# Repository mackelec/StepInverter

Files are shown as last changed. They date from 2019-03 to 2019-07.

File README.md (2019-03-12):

# StepInverter
These are the Files and Tools for my Step Inverter based on Tony's (WarpSpeed) designs and ideas.
You'll find me, "MackOffGrid" and Tony, "WarpSpeed" on https://www.thebackshed.com/forum/forum_topics.asp?FID=4 

Please keep in mind that the spreadsheet, software and schematics are not polished for public consumption, I created them for myself to get the job done.

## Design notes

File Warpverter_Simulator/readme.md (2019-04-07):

# Warpverter Simulator

The simulator reads the signals from a Warpverter of any kind, and produces an analog output that you can view using a Scope.  It can also capture a frame of data and send the data to a PC.

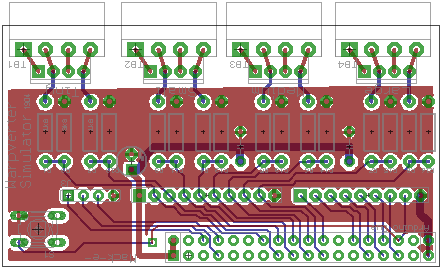
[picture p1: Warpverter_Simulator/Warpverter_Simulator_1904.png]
Warpverter Simulator


## Instruction

This PCB plugs into the 38 pin header of tha Aduno DUE.

Then plug the outputs of Tony's Inverter, or stm32_Warpverter, into the matching connectors of the simulator PCB.
Connect your oscilloscope to DAC0 of the DUE to see the synthesized waveform.

Press the button on the simulator PCB and it will grab a frame of data and send it (by USB) to your PC.  Using the Arduino IDE serial monitor is the easiest way.

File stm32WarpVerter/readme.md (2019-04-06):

# stm32_WarpVerter

This project is based on Tony's "WarpSpeed" inverter, aka the "WarpVerter"

This version is processor based, on the STM32F103 BluePill module.

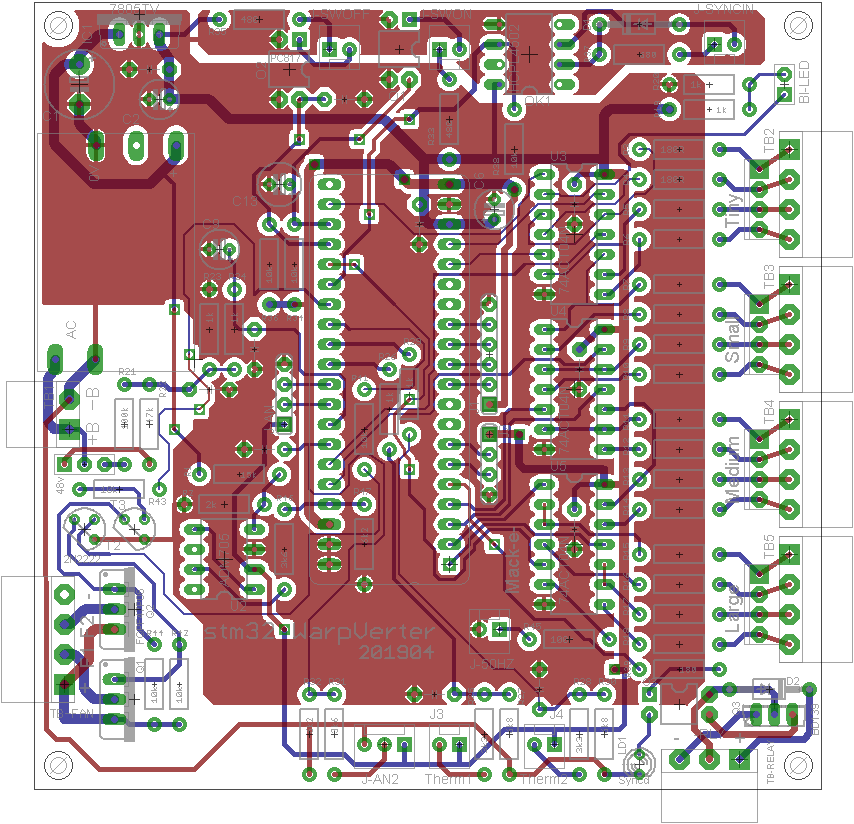
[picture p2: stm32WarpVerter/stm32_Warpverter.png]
stm32WarpVerter


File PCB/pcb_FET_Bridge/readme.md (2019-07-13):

# MOSFET Bridge PCB  

This PCB can be used as a Full H-Bridge or Half H-Bridge board.  Fet Driver board required.

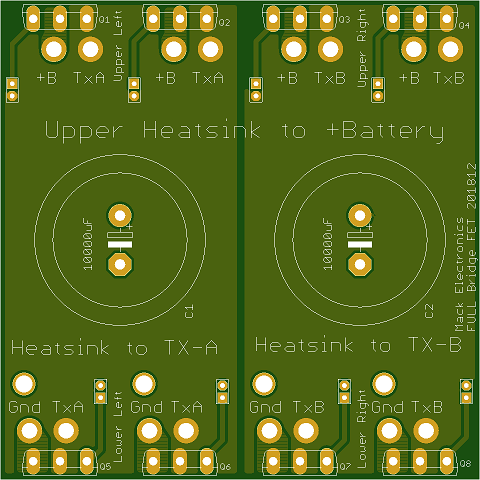
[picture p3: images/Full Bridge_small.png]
Full Bridge


#### Last Tested PCB

[Zip - Gerbers, Cad files 201812](https://github.com/mackelec/StepInverter/blob/master/PCB/pcb_FET_Bridge/FullBridgeFet_201812_2_complete.zip)

## Most Recent Version

 -  #### FBF_4Pin_201907-A
 -  Driver board connectors have been changed to 4 pin connectors.
 -  100k SMD (1206) Pulldowns added.  Not required - precautionary.
 -  Added Large Capacitor with Screw Terminals, (ALS70A513NF100 )[https://au.mouser.com/ProductDetail/80-ALS70A513NF100]
 -  [Zip - Gerbers, Cad Files FBF_4pin_201907](https://github.com/mackelec/StepInverter/blob/master/PCB/pcb_FET_Bridge/FullBridgeFet_4pin_201907A_complete.zip)
 -  Should be compatible with 2 Pin Driver Board.
 
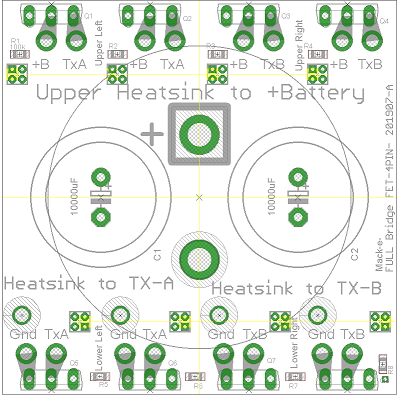
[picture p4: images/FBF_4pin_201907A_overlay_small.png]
FBF_4Pin_201907-A


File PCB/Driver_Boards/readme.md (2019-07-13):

#  Full Bridge Driver Board (201907-A)

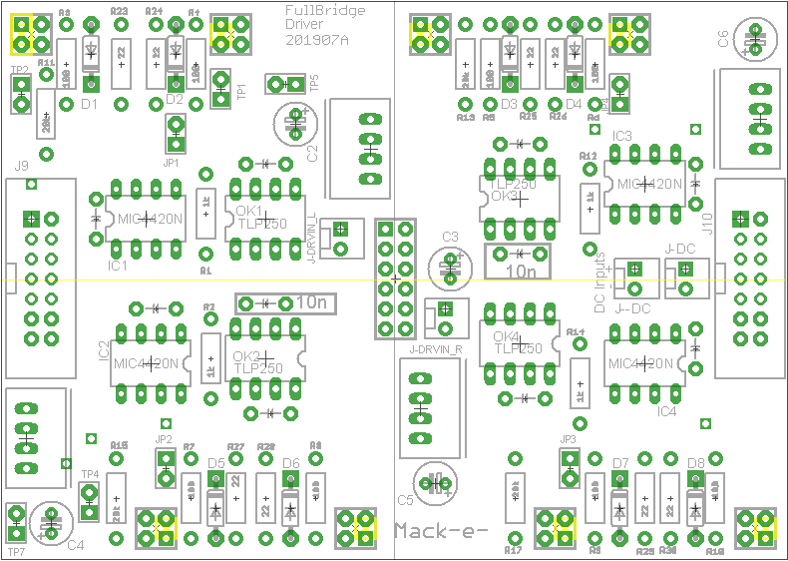
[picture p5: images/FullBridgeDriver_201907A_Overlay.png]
FullBridgeDriverBoard


#  Half Bridge Driver Board (201907)

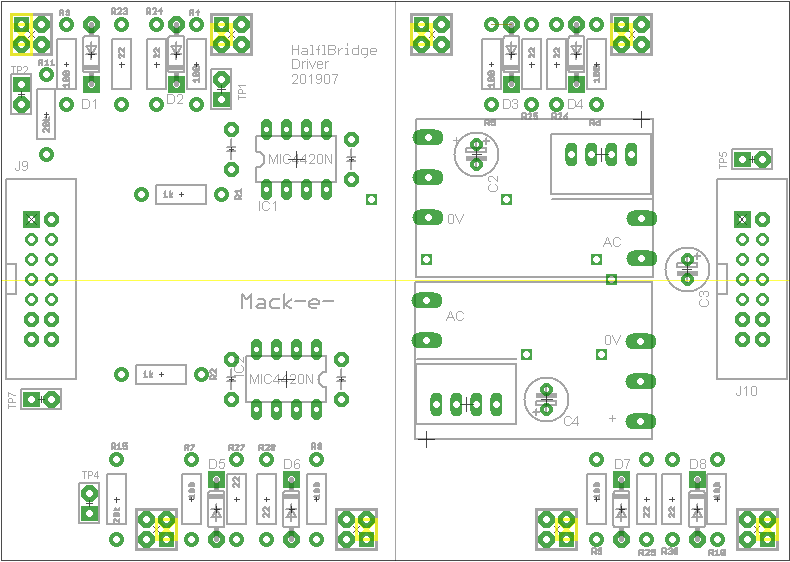
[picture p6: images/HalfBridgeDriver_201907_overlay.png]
HalfBridgeDriverBoard


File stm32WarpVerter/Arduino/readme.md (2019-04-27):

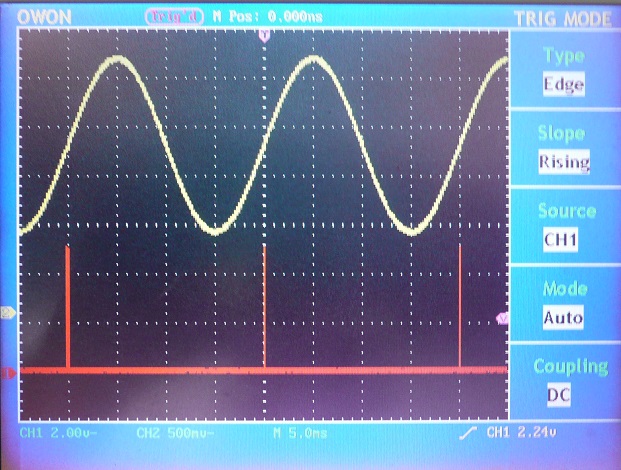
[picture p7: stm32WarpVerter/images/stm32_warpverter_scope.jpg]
Inverter View
 

###  Arduino Software

The software for the stm32_Warpverter is separated into two projects.

* # stm32_Warpverter project.  
  * This is the software which runs the stm32_Warpverter.  
  * The latest version is [stm32_warpverter_009](https://github.com/mackelec/StepInverter/tree/master/stm32WarpVerter/Arduino/stm32_Warpverter/stm32_Warpverter_009)
  *  This software runs on stm32F103C8 "Blue Pill" and the [stm32_Warpverter PCB](https://github.com/mackelec/StepInverter/tree/master/stm32WarpVerter/PCB).
  *  The STM32 BluePill has a generous Flash Rom capacity - notional 64k but most seem to have 128k. This software makes extensive use of pre-calculated lookup tables making full use of available Flash Rom..  
  *  Tables are produced by the "Print_Tables" arduino software.  See Next Section.  
  *  Comprises all the features you need in a functional Inverter.
  *  Most features are configurable - mostly in the Print_Tables software.

* # Print_Tables project.  
  *  The latest version is [print_Tables_2c](https://github.com/mackelec/StepInverter/tree/master/stm32WarpVerter/Arduino/Print_Tables/print_Tables_02).
  *  The objective of this software is to take the User Settings and create "Tables" in the form of arrays.  
  *  The USER_Settings tab holds various setting that may be adjusted.  
  *  Upload and run the program on the BluePill.  
  *  The BluePill creates the required "Table" arrays for the stm32_Warpverter and exports the array data to the Serial port.  
  *  From the Serial Monitor the array data is copied and pasted into the stm32_Warpverter project.

## Features

* This software provides the functionality to acheive Tony's "WarpSpeed" Warpverter; a low distortion, four transformer, very low frequency, pure sine wave inverter.
* Open loop control of output voltage based on input voltage and input current.  
* Two 10k thermister inputs and corresponding PWM FAN outputs.  Fully configurable temperatures and control method: modulating PWM or Bang-Bang.
* Seperate ON and OFF inputs.  Off input can be used as external Fault input.
* Bi-Colour LED for ON-OFF status.
* InputCurrent - Fan function.  Two independant Input Current thresholds - when met will operate the two corresponding FANS. 
* Under and Over Input Voltage shut downs (configurable).
* Over Current shut down .
* 50Hz / 60Hz configurable. 
* External Syncronising input.  Using Poida's mains sync routine.  Should sync with other warpVerters accurately.
* 50Hz (60Hz) pulse output (approx 20uSec) will ensure accurate syncronising with other warpVerters.

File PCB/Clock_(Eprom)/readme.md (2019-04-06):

## Warpverter Clock PCB

This PCB contructs is the heart of the Warpverter.  It uses an Eprom to construct the four inverter drive signals.

### VER 201903

This is my latest version. Fixed an oops on the previous version.  Major changes to the micro port, uses a crystal module instead of a discrete circuit, added a sync connector for my experiment on three phase.  Added a Bi-colour LED for Run/Stop.  Changed the PSU supervisor to max705.

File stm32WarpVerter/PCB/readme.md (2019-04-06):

Zip Files contain EAGLE files and Gerber files.

For gerber viewer,  http://gerbv.geda-project.org/

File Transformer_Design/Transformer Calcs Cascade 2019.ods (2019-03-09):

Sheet: Cascade Design
Nominal Battery Voltage | 26.5
Vmax | 28
Vmin | 24
Nominal AC Voltage | 240
Nominal Power | 4500
Num Transformer Stages | 4
 |  |  |  | 4500 W |  | 3000 W |  | 1500 W |  | 500 W
Transformer # | Nom. Step Voltage | Nom RMS Voltage | Power | Cu Loss | Volt Drop | Cu Loss | Volt Drop | Cu Loss | Volt Drop | Cu Loss | Volt Drop
Tx1 | 229.068 | 162 | 3037.5 | 158 | 3 | 70 | 2 | 18 | 1 | 2 | 0
Tx2 | 76.356 | 54 | 1012.5 | 79 | 3 | 35 | 2 | 9 | 1 | 1 | 0
Tx3 | 25.452 | 18 | 337.5 | 39 | 2 | 17 | 1 | 4 | 1 | 0 | 0
Tx4 | 8.484 | 6 | 112.5 | 12 | 1 | 5 | 1 | 1 | 0 | 0 | 0
sum (check) | 339.36 | 240 | 4500 | 288 | 9 | 128 | 6 | 32 | 3 | 4 | 1
RMS (check) | 240
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

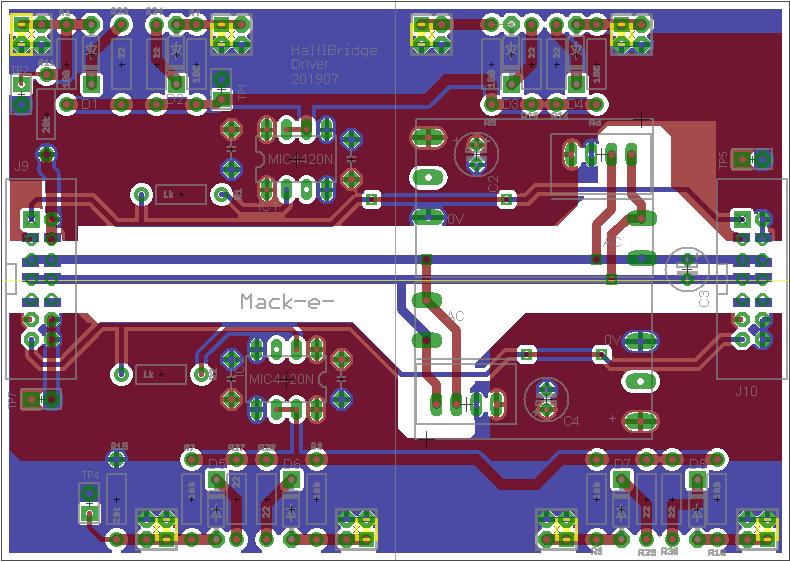
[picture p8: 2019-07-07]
images/HalfBridgeDriver_201907.png

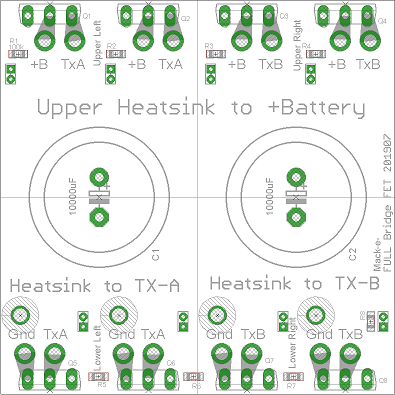
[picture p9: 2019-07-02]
images/FBF_201907_small.png

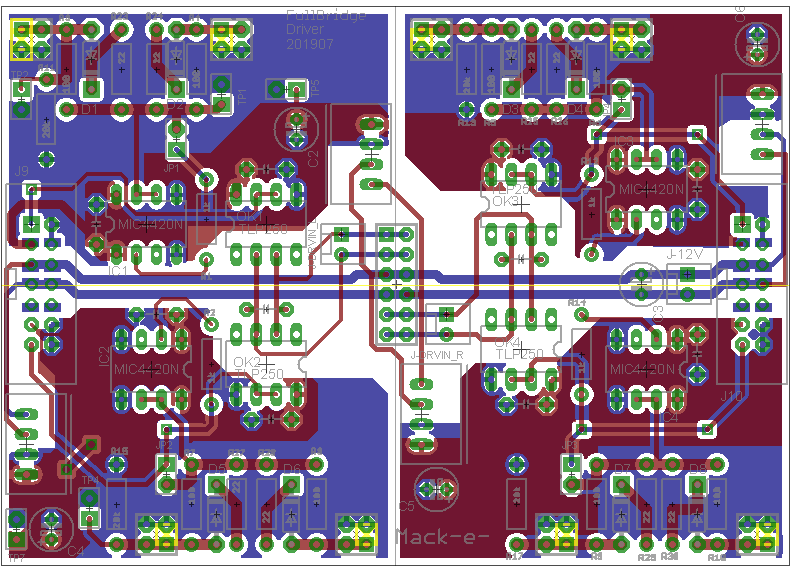
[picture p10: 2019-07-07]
images/FullBridgeDriver_201907.png

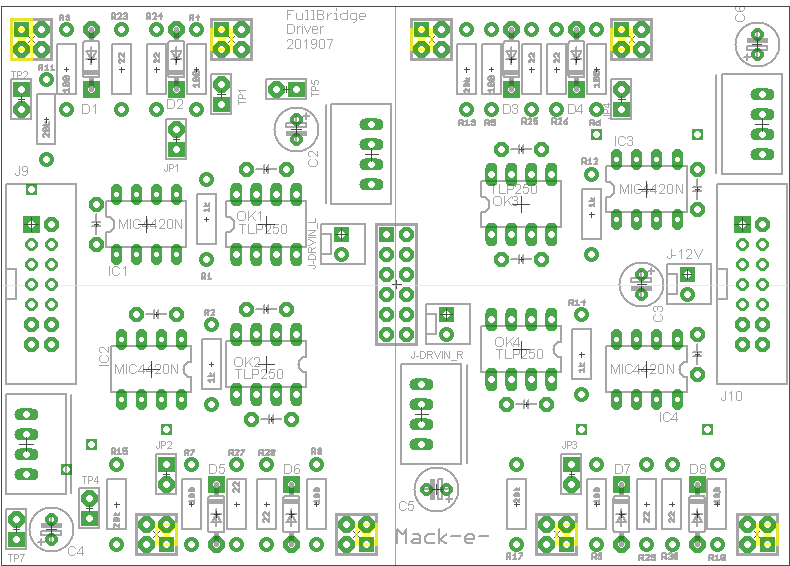
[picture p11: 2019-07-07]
images/FullBridgeDriver_201907_Overlay.png

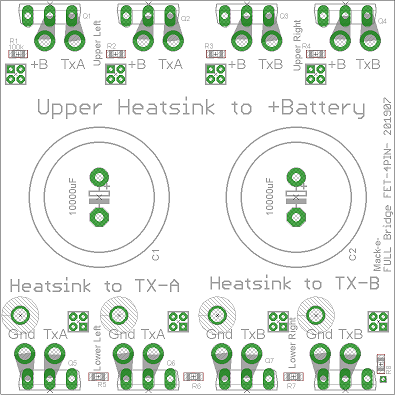
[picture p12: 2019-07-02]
images/FBF_4pin_201907_small.png

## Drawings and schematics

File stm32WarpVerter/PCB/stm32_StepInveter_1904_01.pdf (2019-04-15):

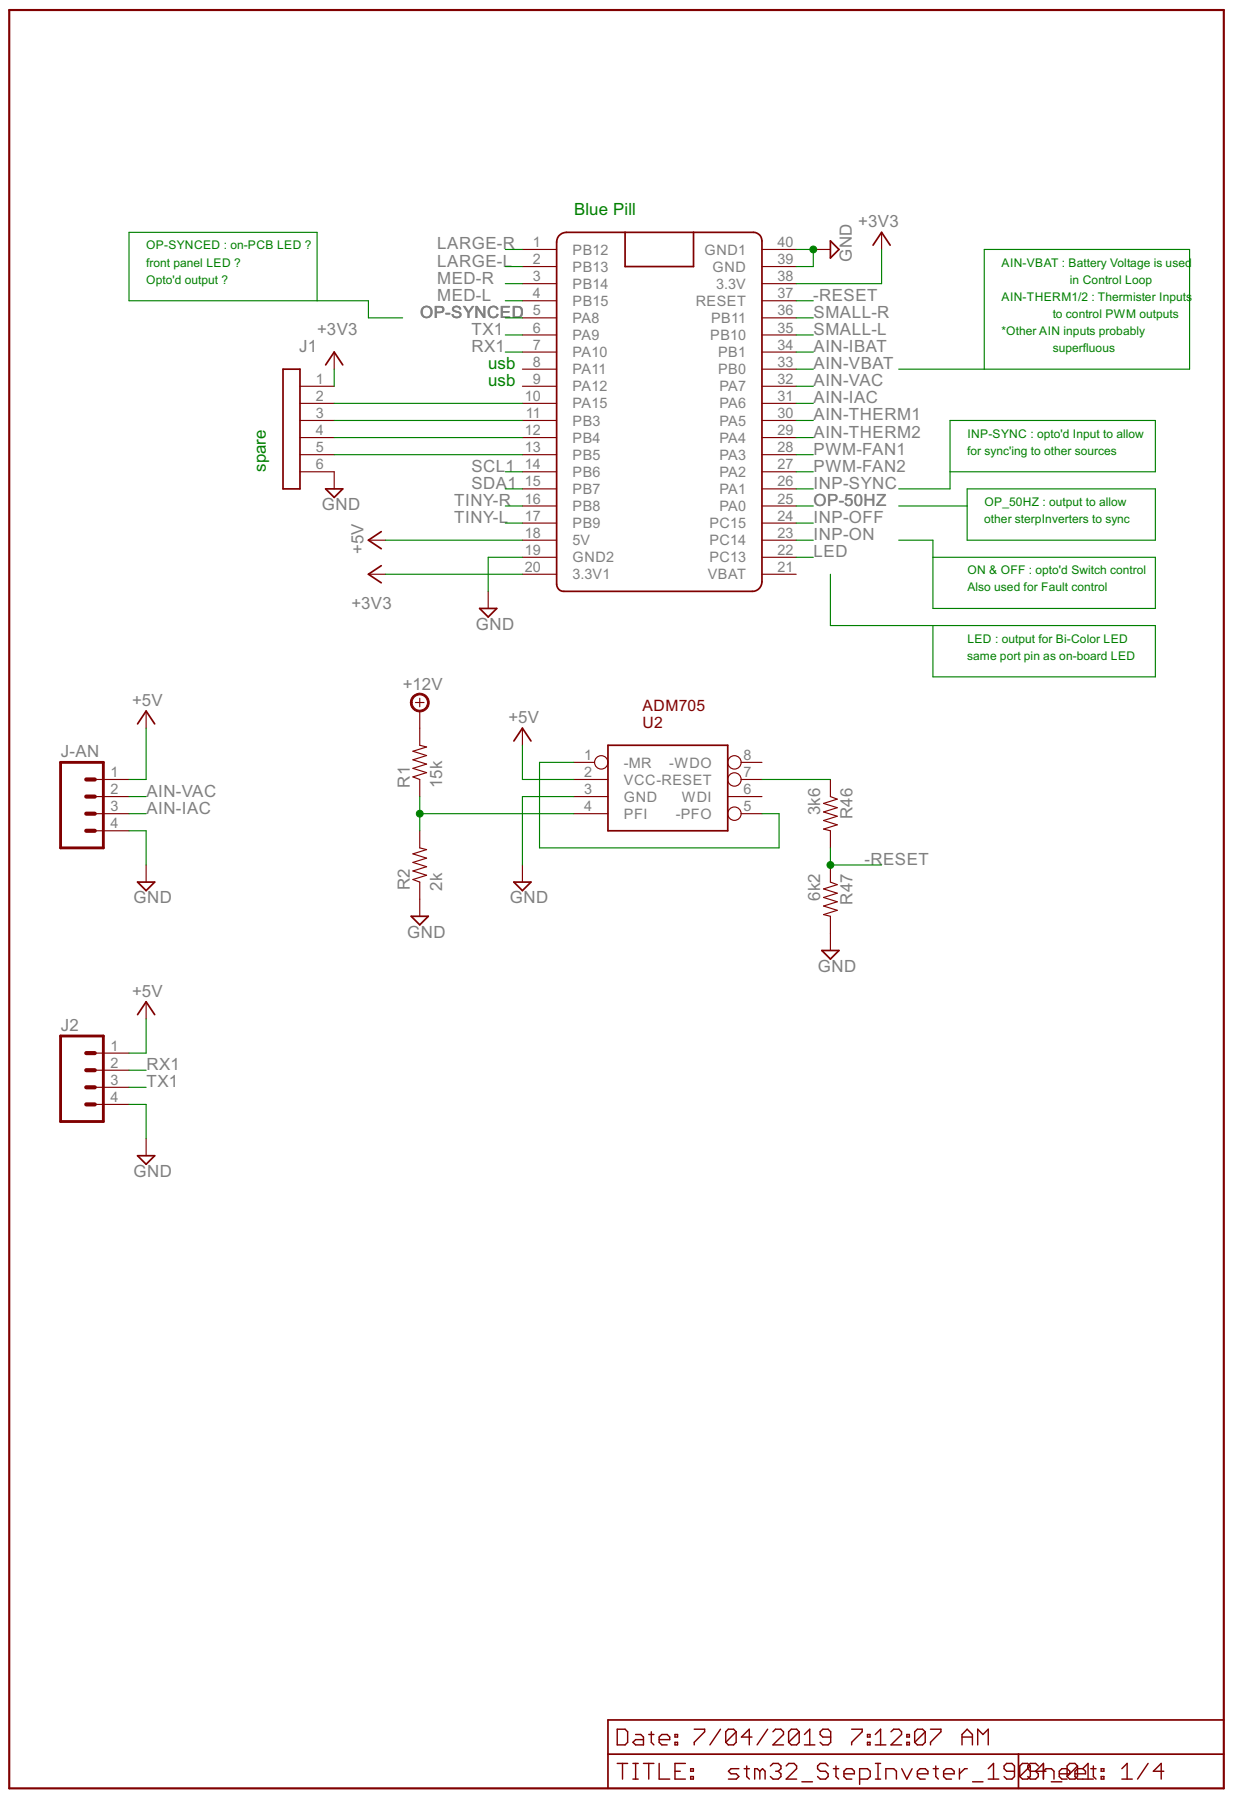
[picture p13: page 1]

OP-SYNCED : on-PCB LED ?

in Control Loop AIN-THERM1/2 : Thermister Inputs

*Other AIN inputs probably

to control PWM outputs

INP-SYNC : opto'd Input to allow
for sync'ing to other sources

OP_50HZ : output to allow
other sterpInverters to sync ON & OFF : opto'd Switch control Also used for Fault control LED : output for Bi-Color LED

same port pin as on-board LED

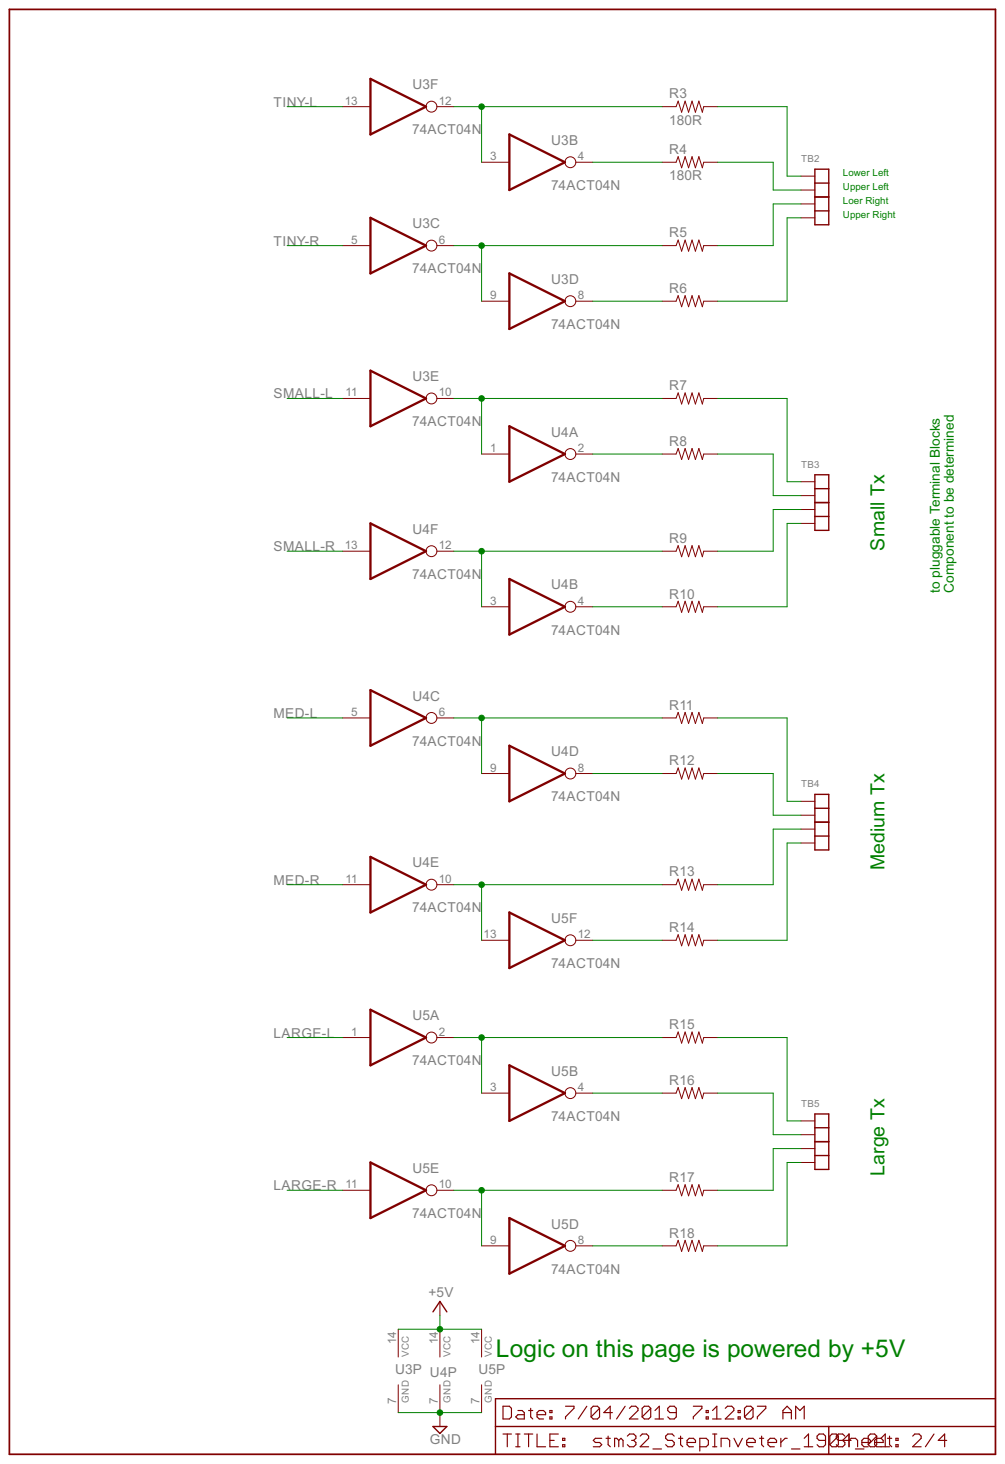
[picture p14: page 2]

Lower Left Upper Left Loer Right Upper Right

to pluggable Terminal Blocks Component to be determined

Logic on this page is powered by +5V

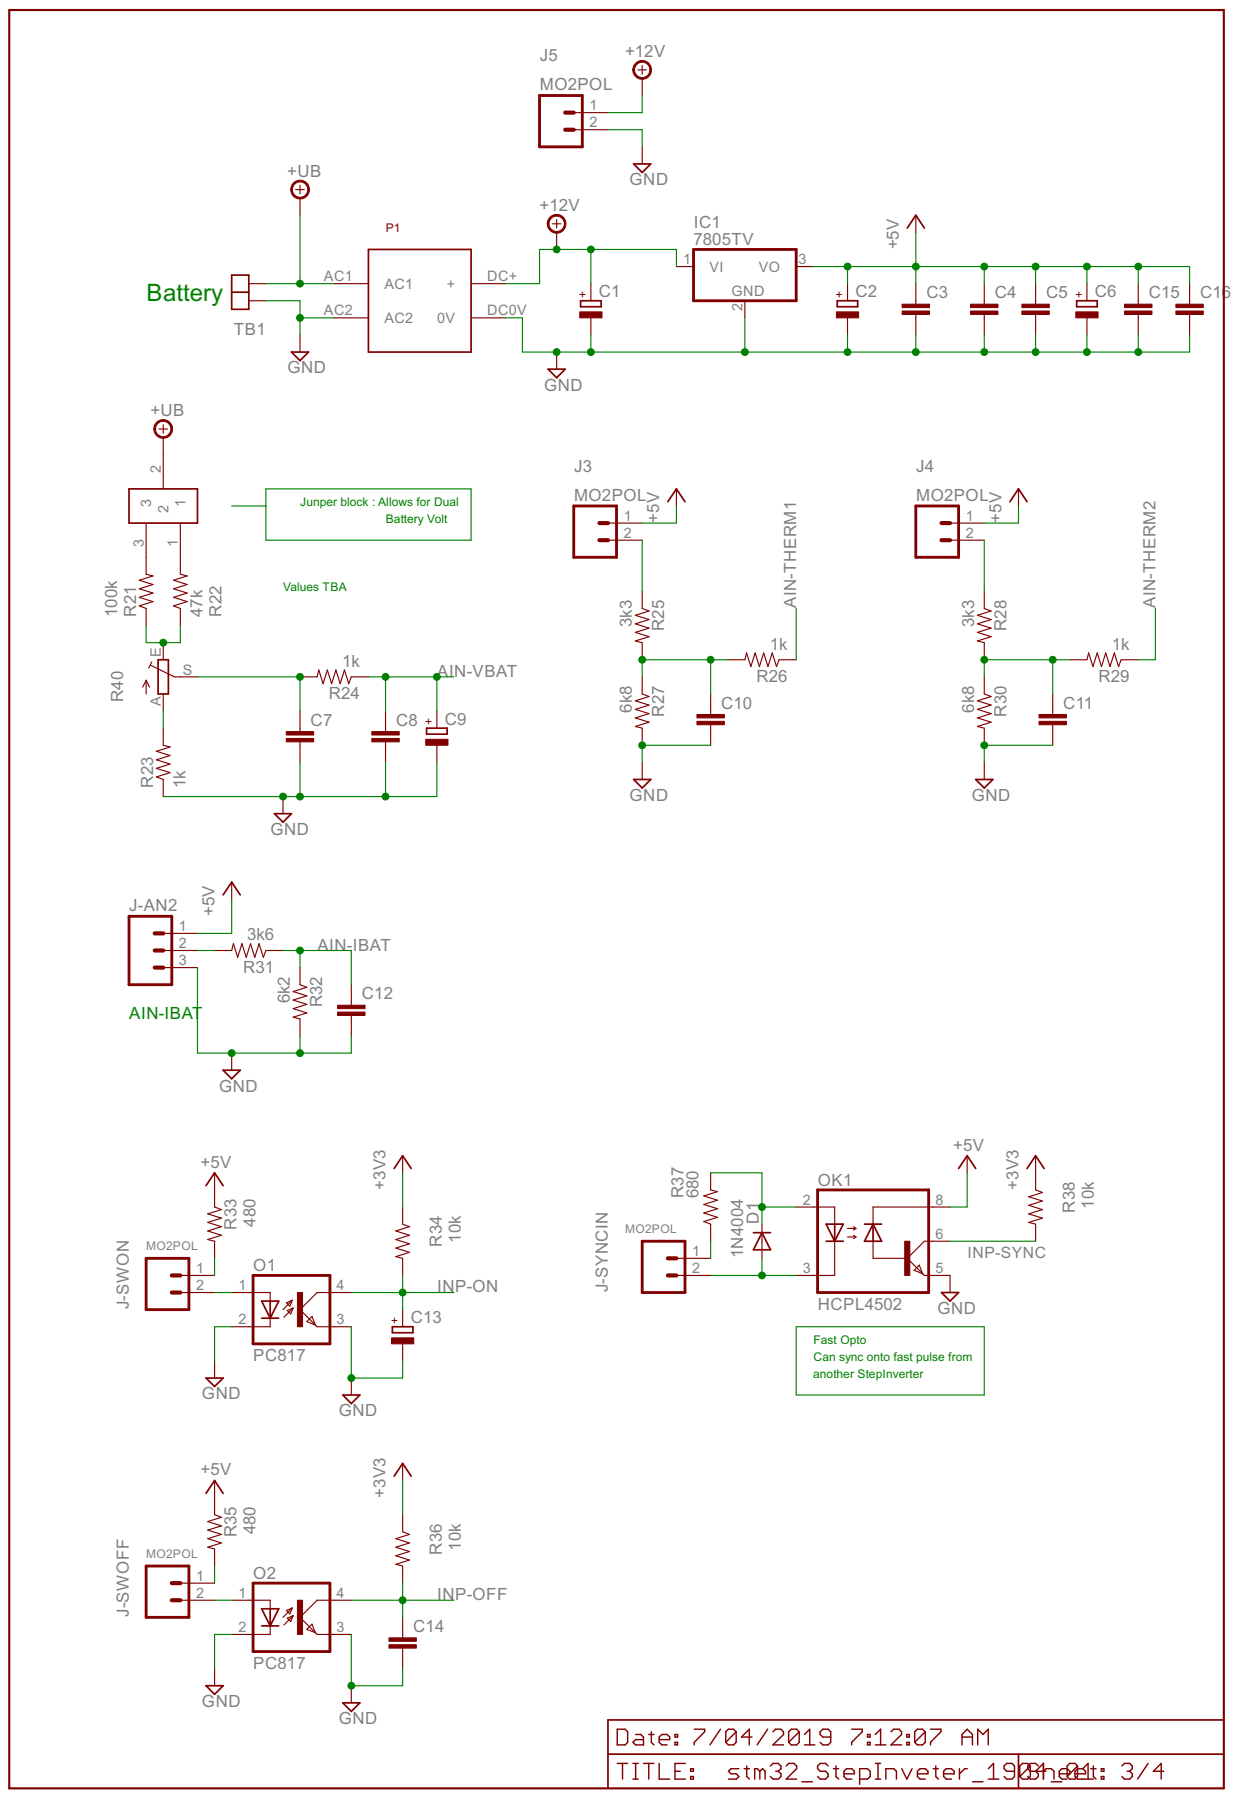
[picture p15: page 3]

Junper block : Allows for Dual Battery Volt

Fast Opto Can sync onto fast pulse from

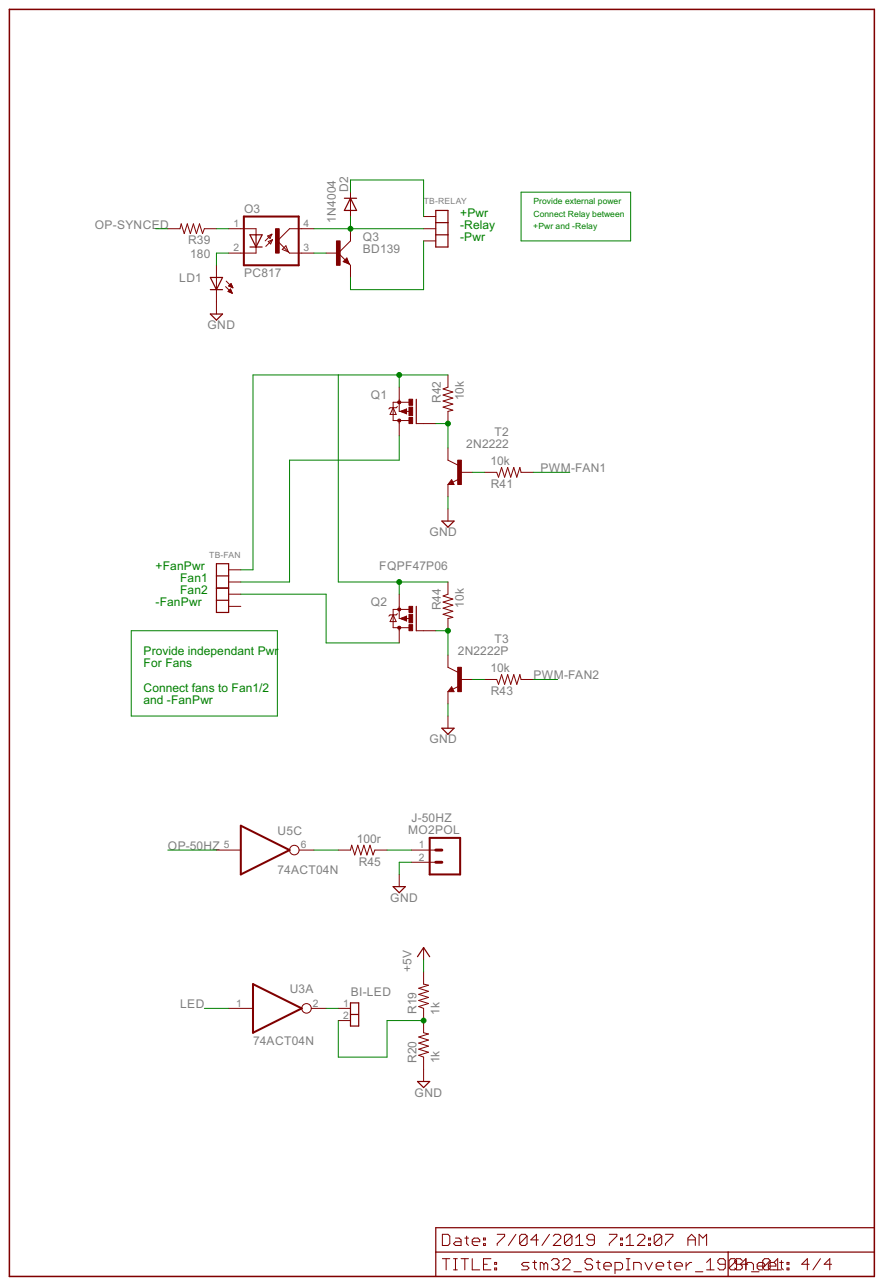
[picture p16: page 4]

Provide independant Pwr For Fans Connect fans to Fan1/2

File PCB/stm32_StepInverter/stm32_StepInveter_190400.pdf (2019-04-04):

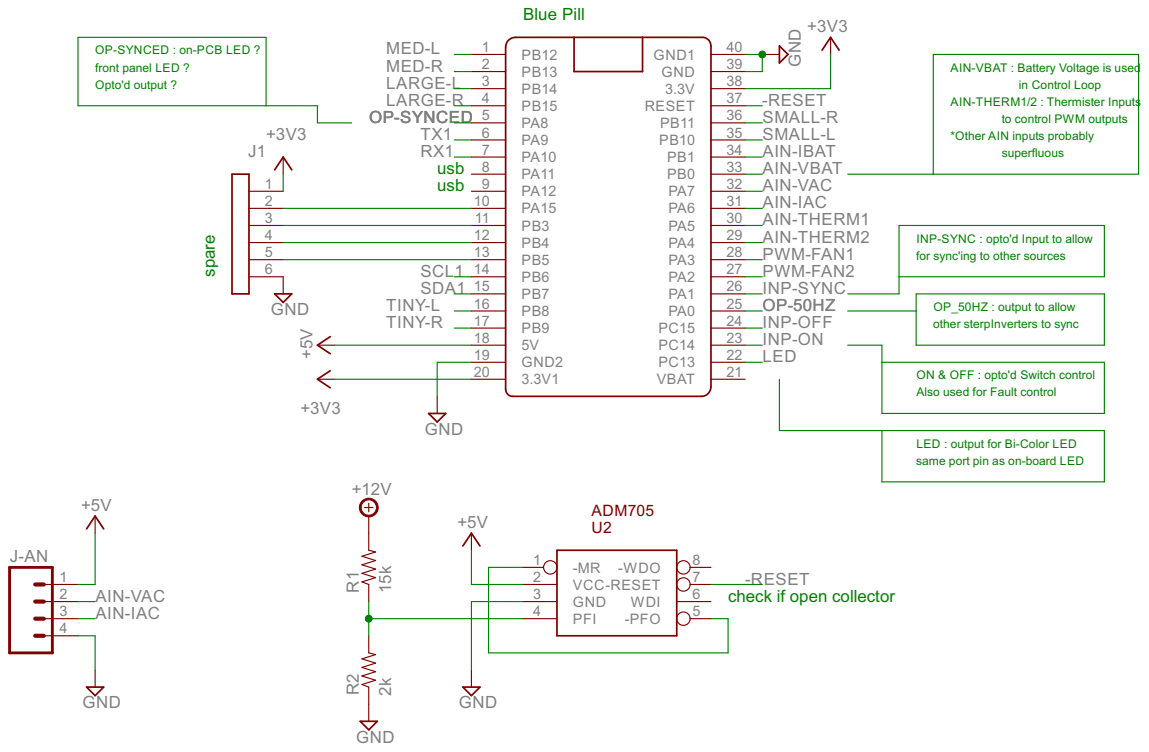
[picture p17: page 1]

OP-SYNCED : on-PCB LED ?

in Control Loop AIN-THERM1/2 : Thermister Inputs

*Other AIN inputs probably

to control PWM outputs

INP-SYNC : opto'd Input to allow
for sync'ing to other sources

OP_50HZ : output to allow
other sterpInverters to sync ON & OFF : opto'd Switch control Also used for Fault control LED : output for Bi-Color LED

same port pin as on-board LED

check if open collector

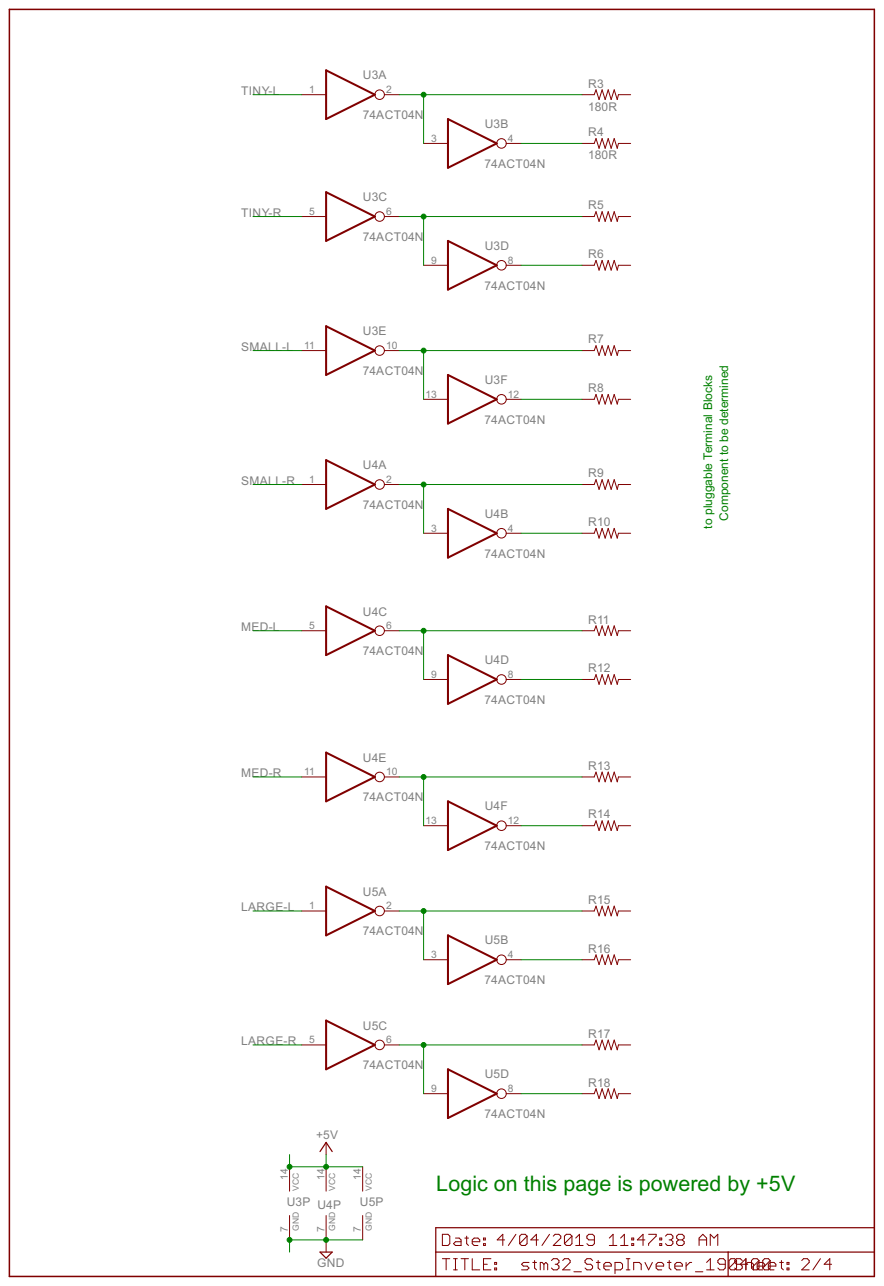
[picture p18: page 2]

to pluggable Terminal Blocks Component to be determined

Logic on this page is powered by +5V

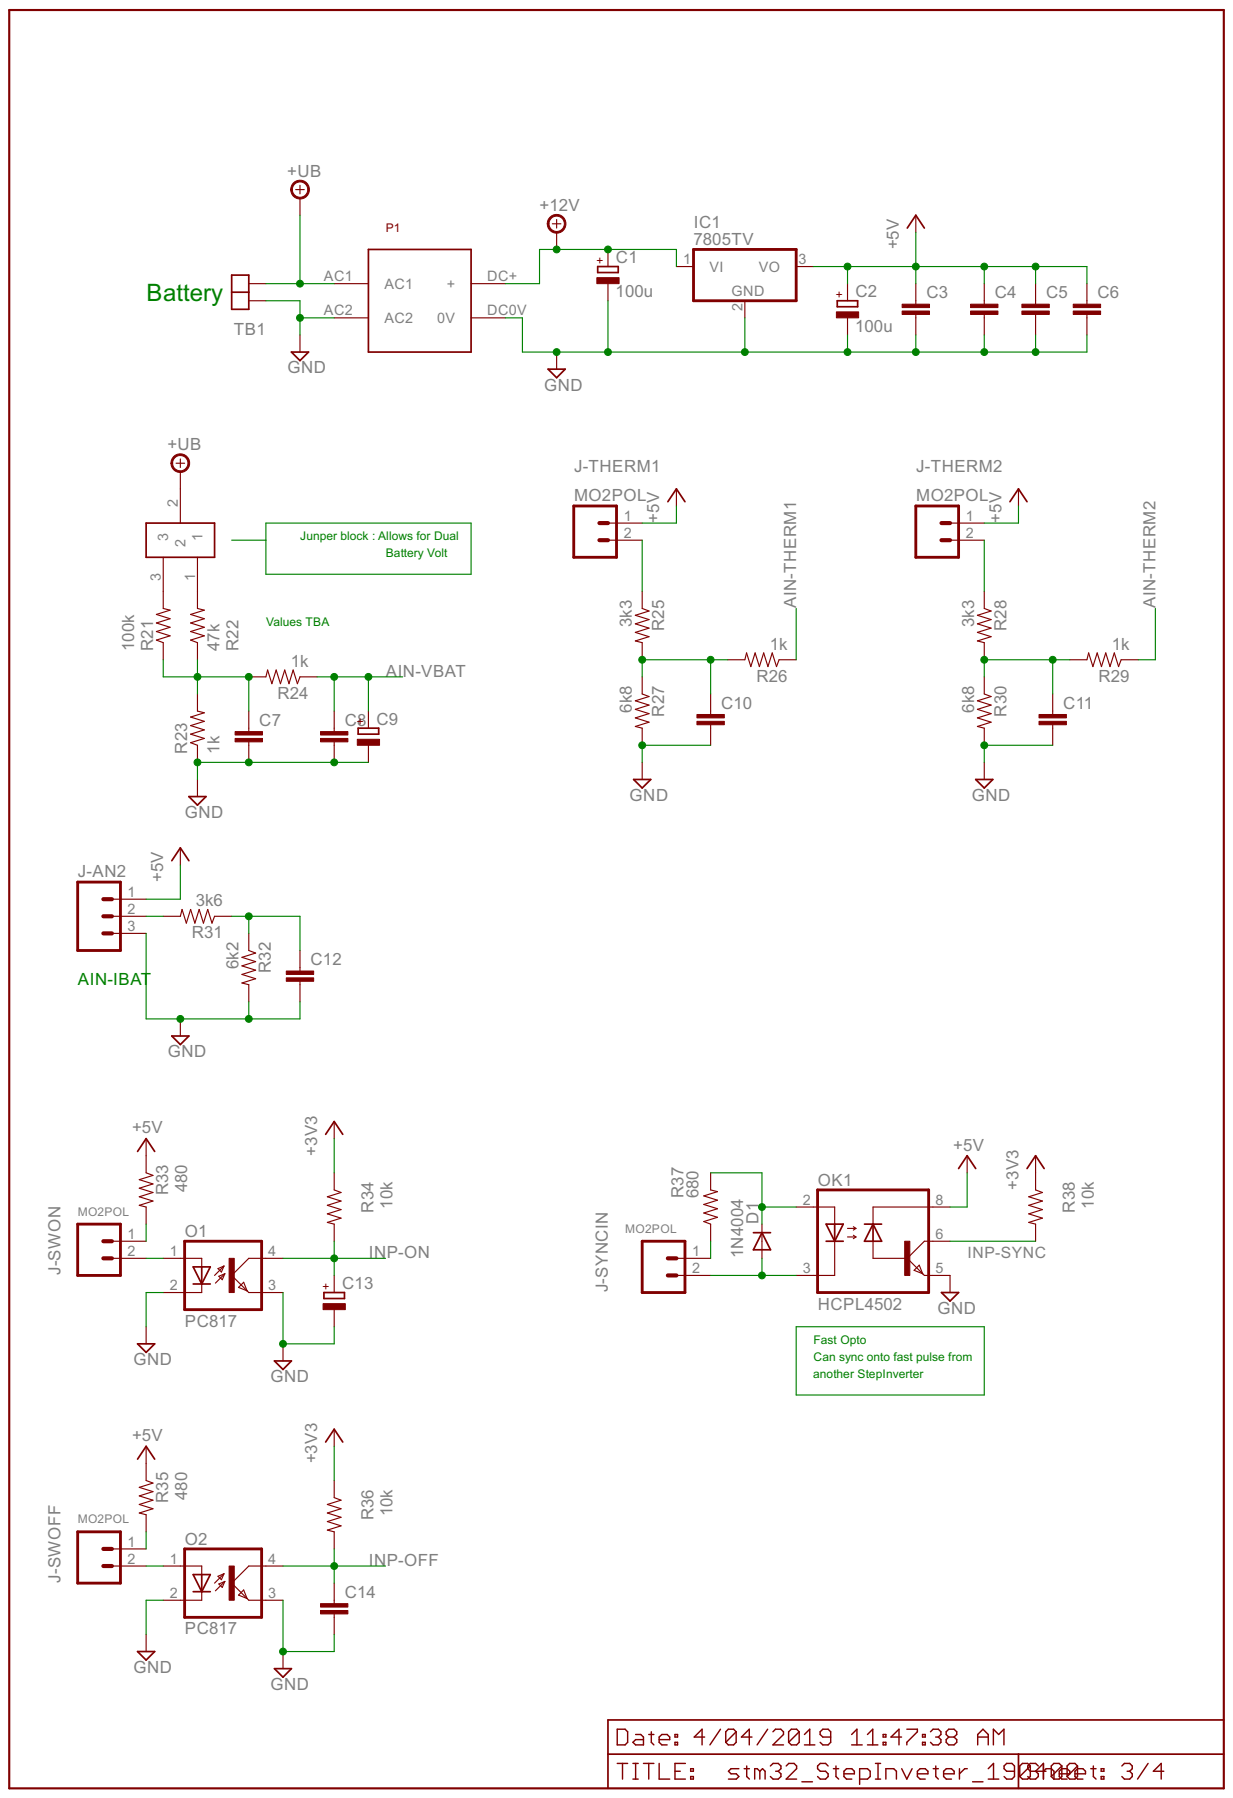
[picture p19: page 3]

Junper block : Allows for Dual Battery Volt

Fast Opto Can sync onto fast pulse from

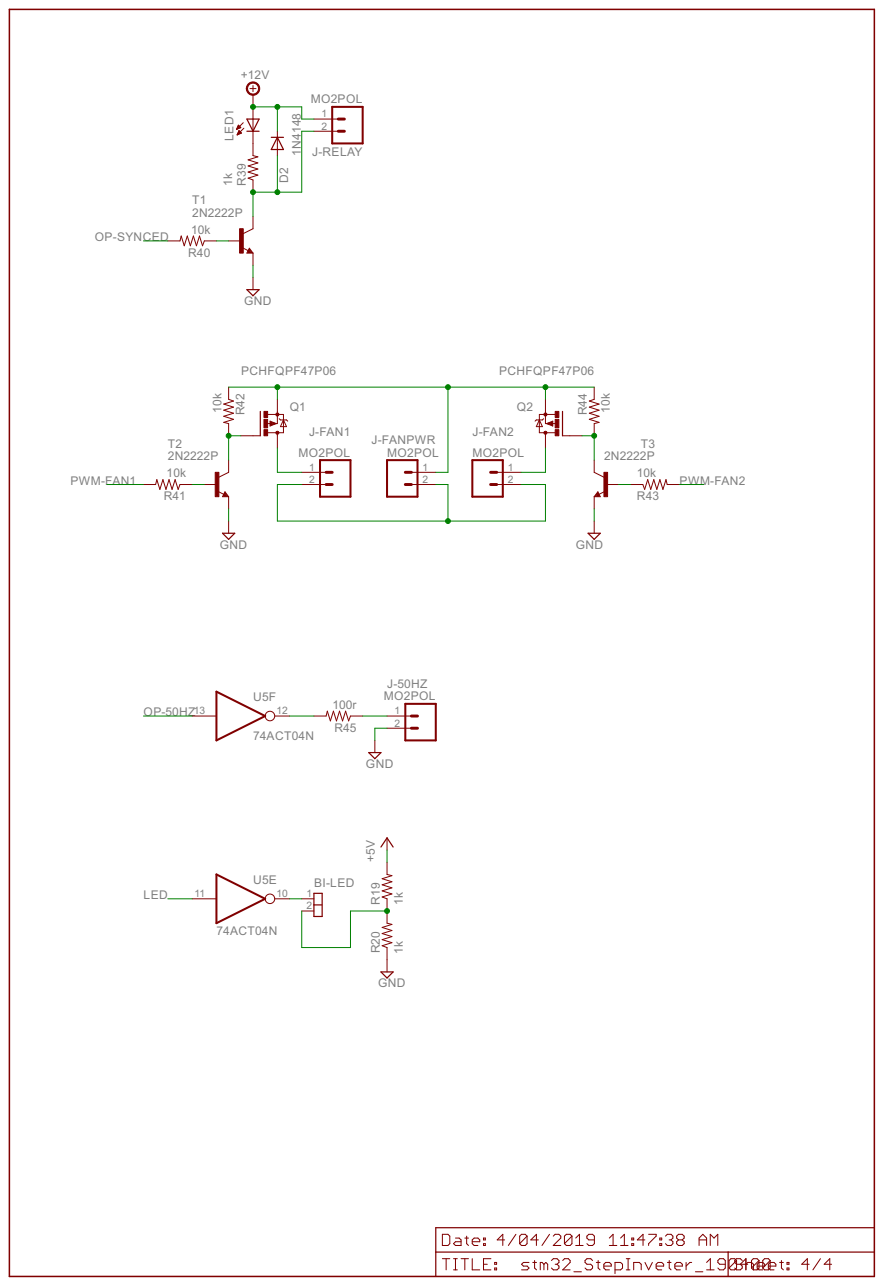
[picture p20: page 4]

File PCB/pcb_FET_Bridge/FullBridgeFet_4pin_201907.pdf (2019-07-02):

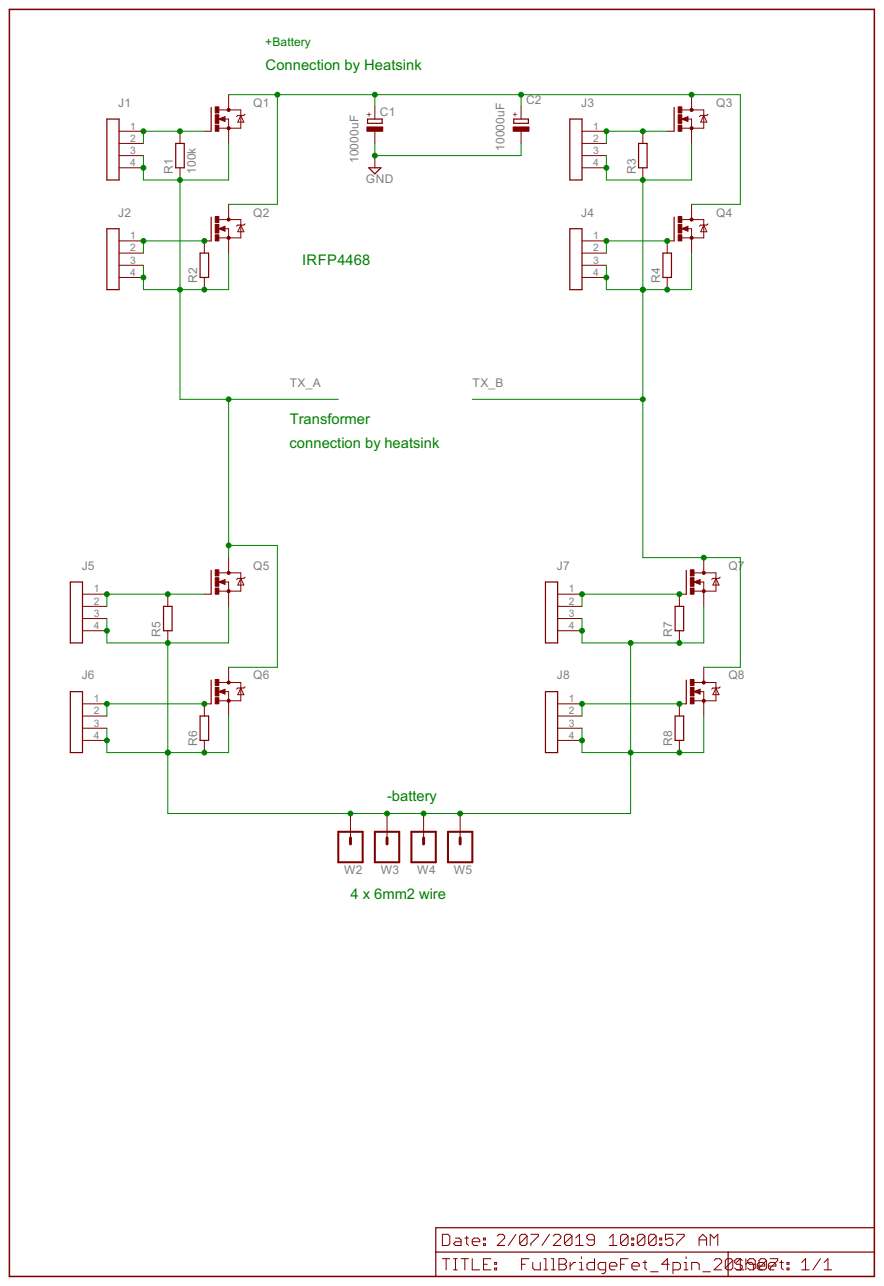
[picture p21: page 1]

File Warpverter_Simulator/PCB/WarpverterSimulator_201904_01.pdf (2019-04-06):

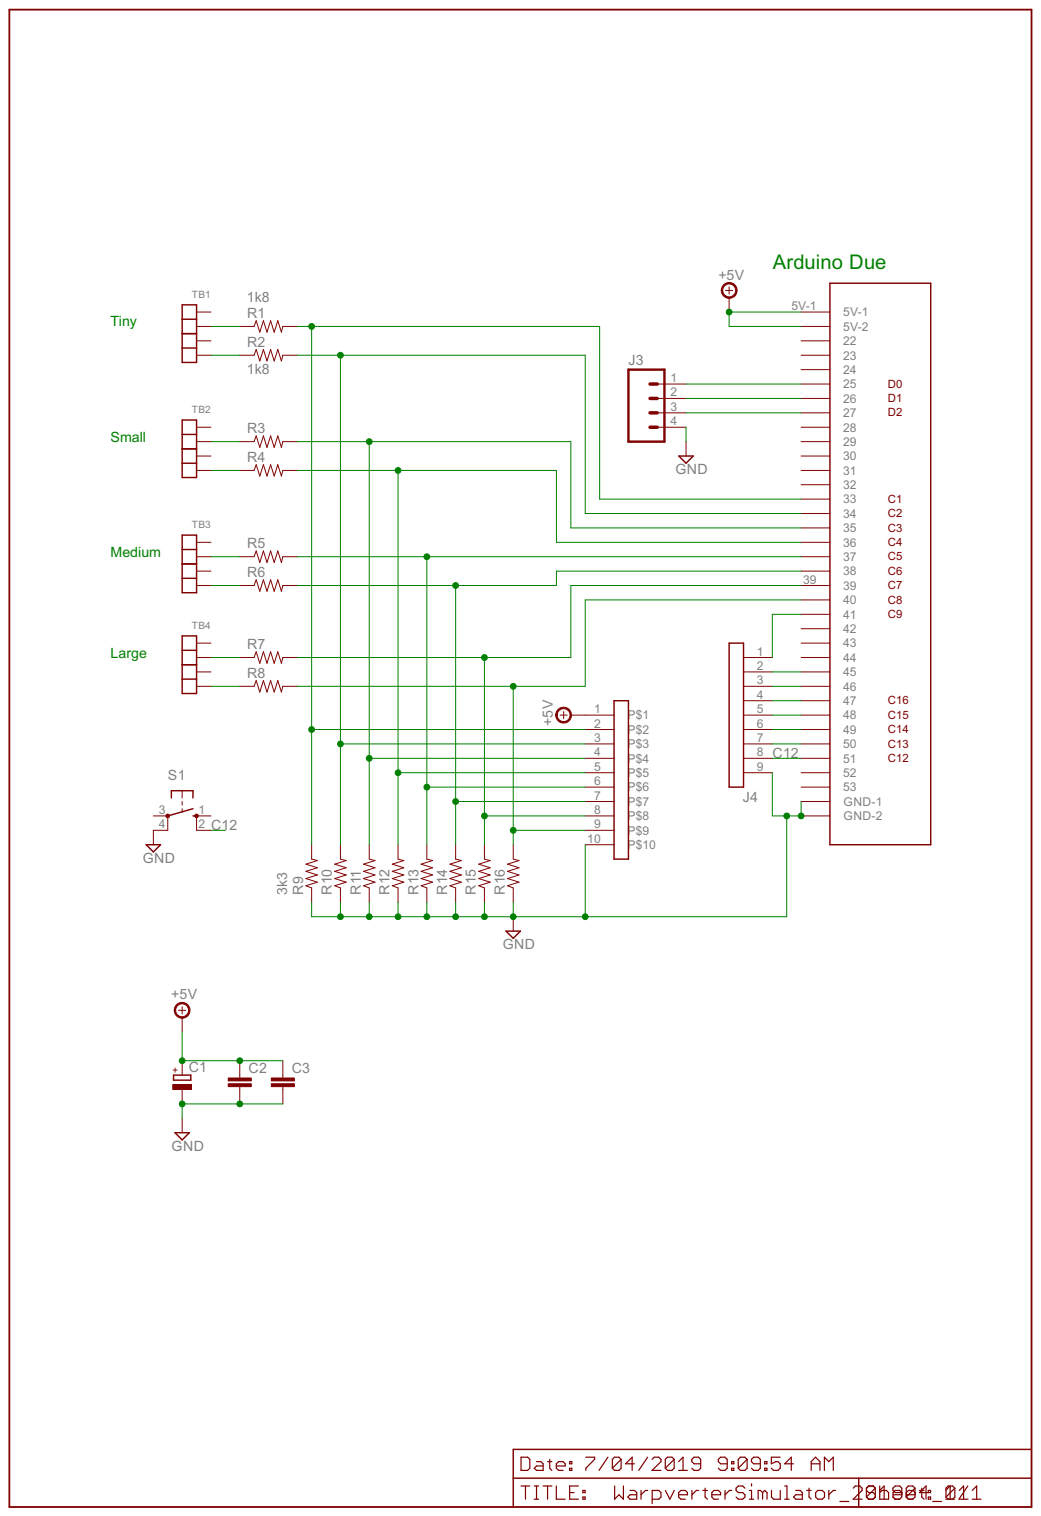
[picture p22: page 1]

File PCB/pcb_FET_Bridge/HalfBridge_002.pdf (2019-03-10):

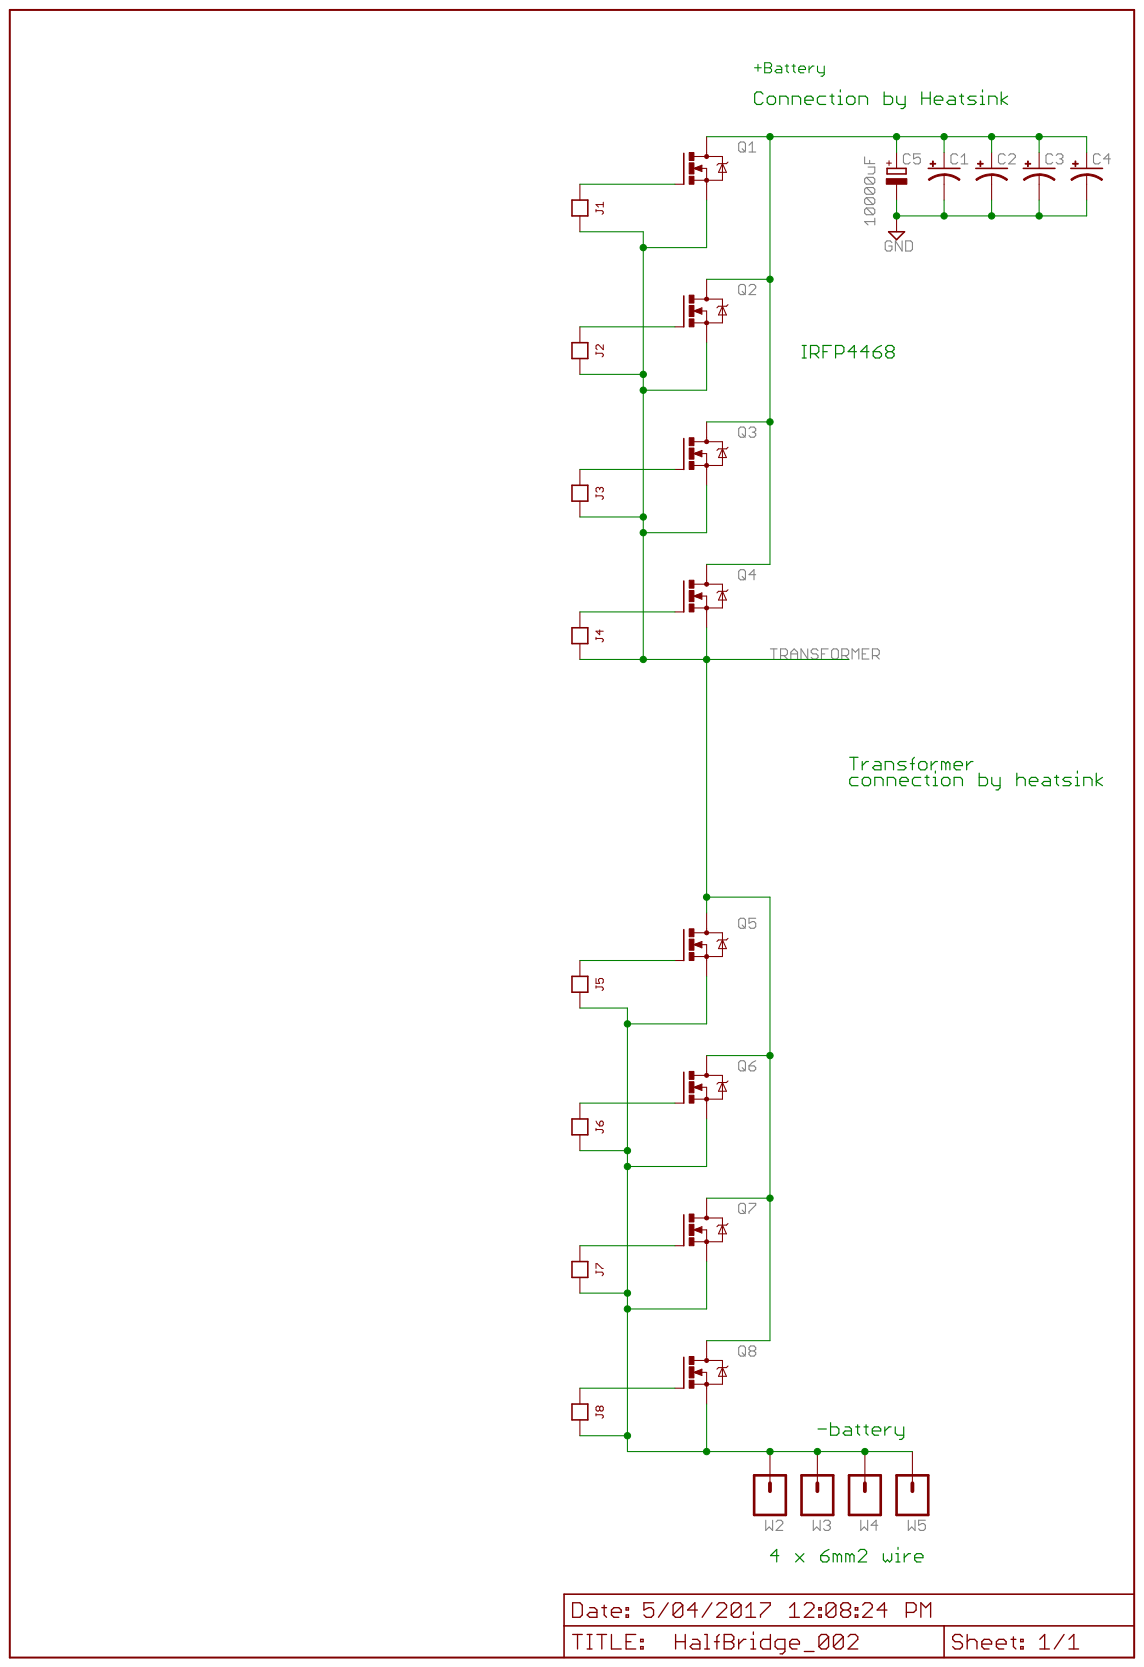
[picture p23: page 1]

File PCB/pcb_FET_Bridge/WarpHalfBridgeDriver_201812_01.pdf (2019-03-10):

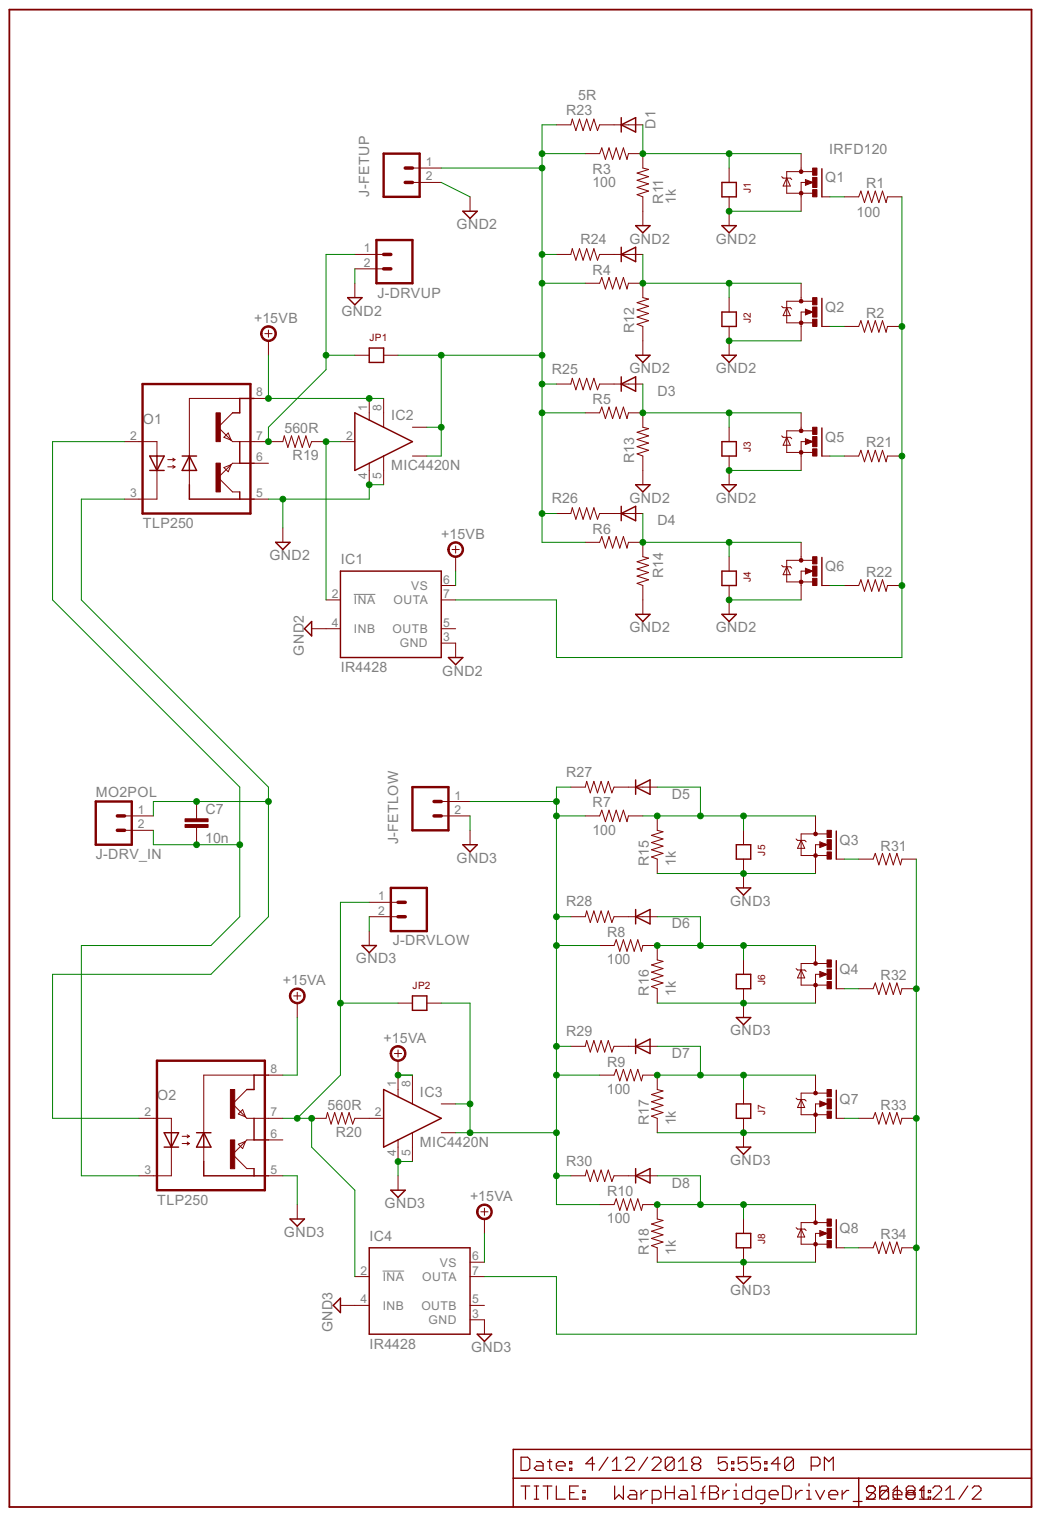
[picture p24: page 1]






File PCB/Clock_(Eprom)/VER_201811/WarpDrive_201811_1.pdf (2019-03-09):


10 A18 | 9 CLK 11 8

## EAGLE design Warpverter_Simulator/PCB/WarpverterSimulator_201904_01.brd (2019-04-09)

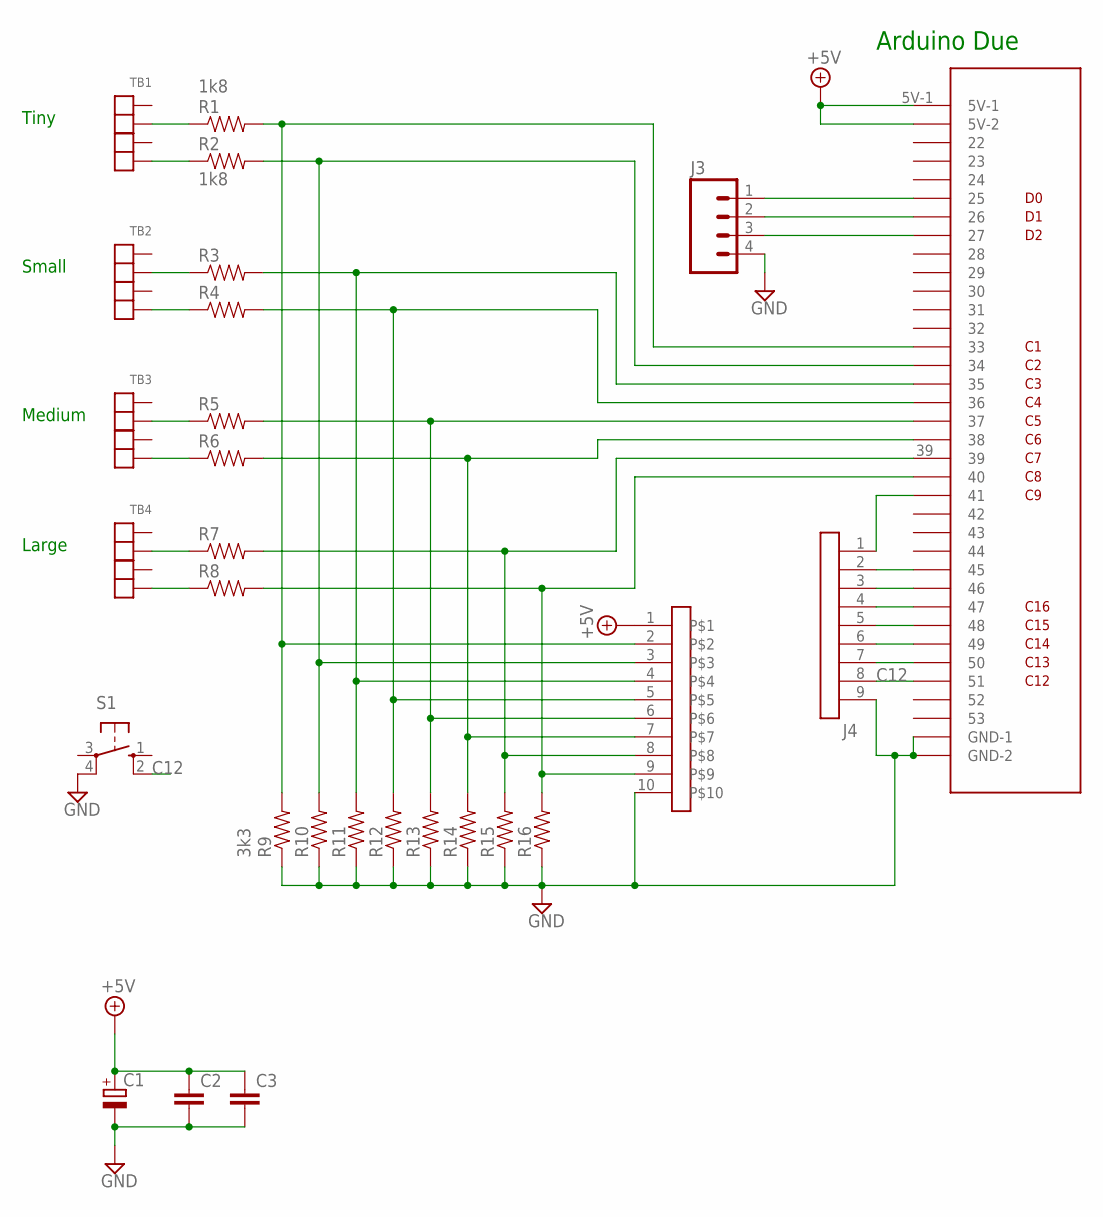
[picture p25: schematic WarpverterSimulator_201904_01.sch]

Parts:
C1: C-RB200100; CPOL-RADIAL-10UF-25V
C2, C3: BCAP
J1: DUE-IDC38
J2: SIL-STACK-10
J3: SIL4
J4: SIL-9
R1, R2: 1k8; AXIAL-0.4
R3, R4, R5, R6, R7, R8, R10, R11, R12, R13, R14, R15, R16: R4; AXIAL-0.4
R9: 3k3; AXIAL-0.4
S1: 10-XX; B3F-10XX
TB1, TB2, TB3, TB4: TB4381_SIL; TB-381-SIL-4P

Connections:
+5V: C1.1 (+), C2.1, C3.1, J1.5V-1, J1.5V-2, J2.1
C12: J1.51, J4.8, S1.2 (S1)
GND: C1.2 (-), C2.2, C3.2, J1.GND-1, J1.GND-2, J2.10, J3.4, J4.9, R9.P$1 (1), R10.P$1 (1), R11.P$1 (1), R12.P$1 (1), R13.P$1 (1), R14.P$1 (1), R15.P$1 (1), R16.P$1 (1), S1.4 (P1)
unnamed: R1.P$1 (1), TB1.2, TB1.12 (2)
unnamed: R2.P$1 (1), TB1.4, TB1.14 (4)
unnamed: R3.P$1 (1), TB2.2, TB2.12 (2)
unnamed: R4.P$1 (1), TB2.4, TB2.14 (4)
unnamed: R5.P$1 (1), TB3.2, TB3.12 (2)
unnamed: R6.P$1 (1), TB3.4, TB3.14 (4)
unnamed: R7.P$1 (1), TB4.2, TB4.12 (2)
unnamed: R8.P$1 (1), TB4.4, TB4.14 (4)
unnamed: J1.33, J2.2, R1.P$2 (2), R9.P$2 (2)
unnamed: J1.34, J2.3, R2.P$2 (2), R10.P$2 (2)
unnamed: J1.35, J2.4, R3.P$2 (2), R11.P$2 (2)
unnamed: J1.36, J2.5, R4.P$2 (2), R12.P$2 (2)
unnamed: J1.37, J2.6, R5.P$2 (2), R13.P$2 (2)
unnamed: J1.38, J2.7, R6.P$2 (2), R14.P$2 (2)
unnamed: J1.39, J2.8, R7.P$2 (2), R15.P$2 (2)
unnamed: J1.40, J2.9, R8.P$2 (2), R16.P$2 (2)
unnamed: J1.25, J3.1
unnamed: J1.26, J3.2
unnamed: J1.27, J3.3
unnamed: J1.50, J4.7
unnamed: J1.49, J4.6
unnamed: J1.48, J4.5
unnamed: J1.47, J4.4
unnamed: J1.46, J4.3
unnamed: J1.45, J4.2
unnamed: J1.41, J4.1

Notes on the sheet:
Tiny
Small
Medium
Large
Arduino Due

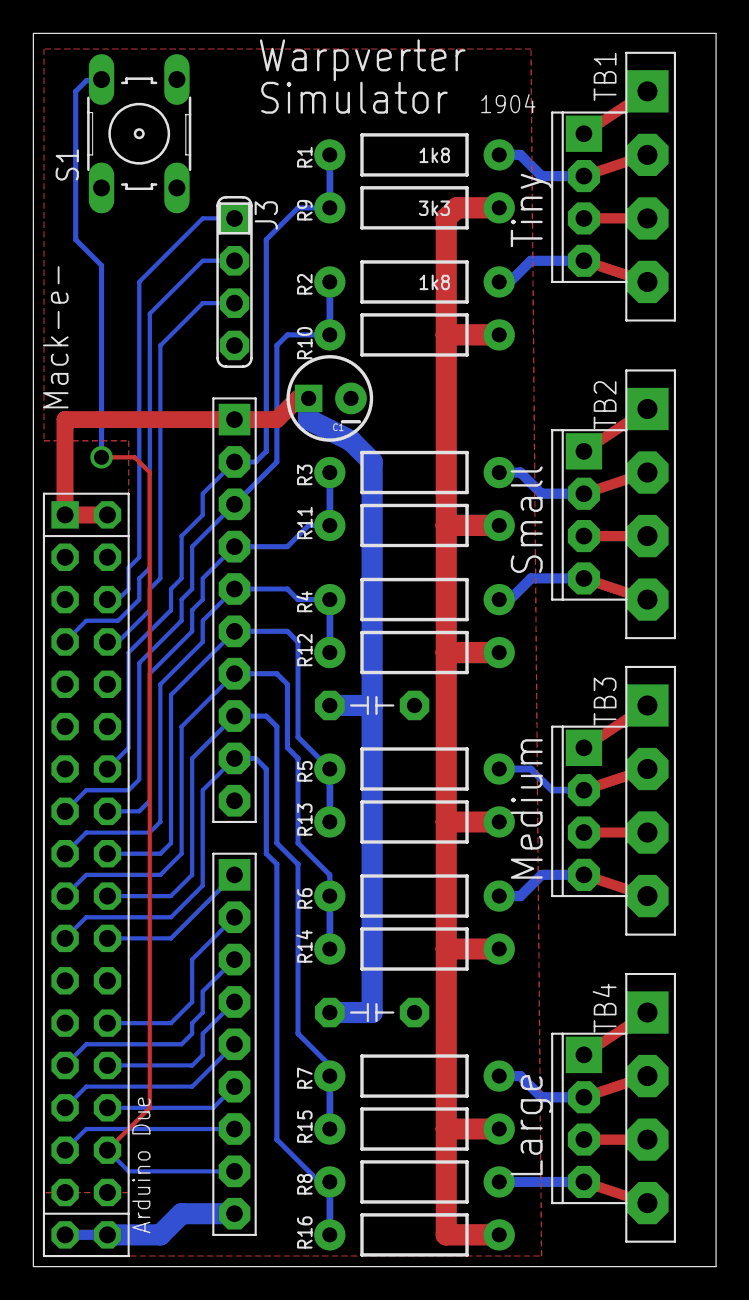
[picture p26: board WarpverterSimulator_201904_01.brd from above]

Board: 2 copper layers, 40.9 x 74.0 mm, 28 parts (0 on the bottom side), 29 nets.

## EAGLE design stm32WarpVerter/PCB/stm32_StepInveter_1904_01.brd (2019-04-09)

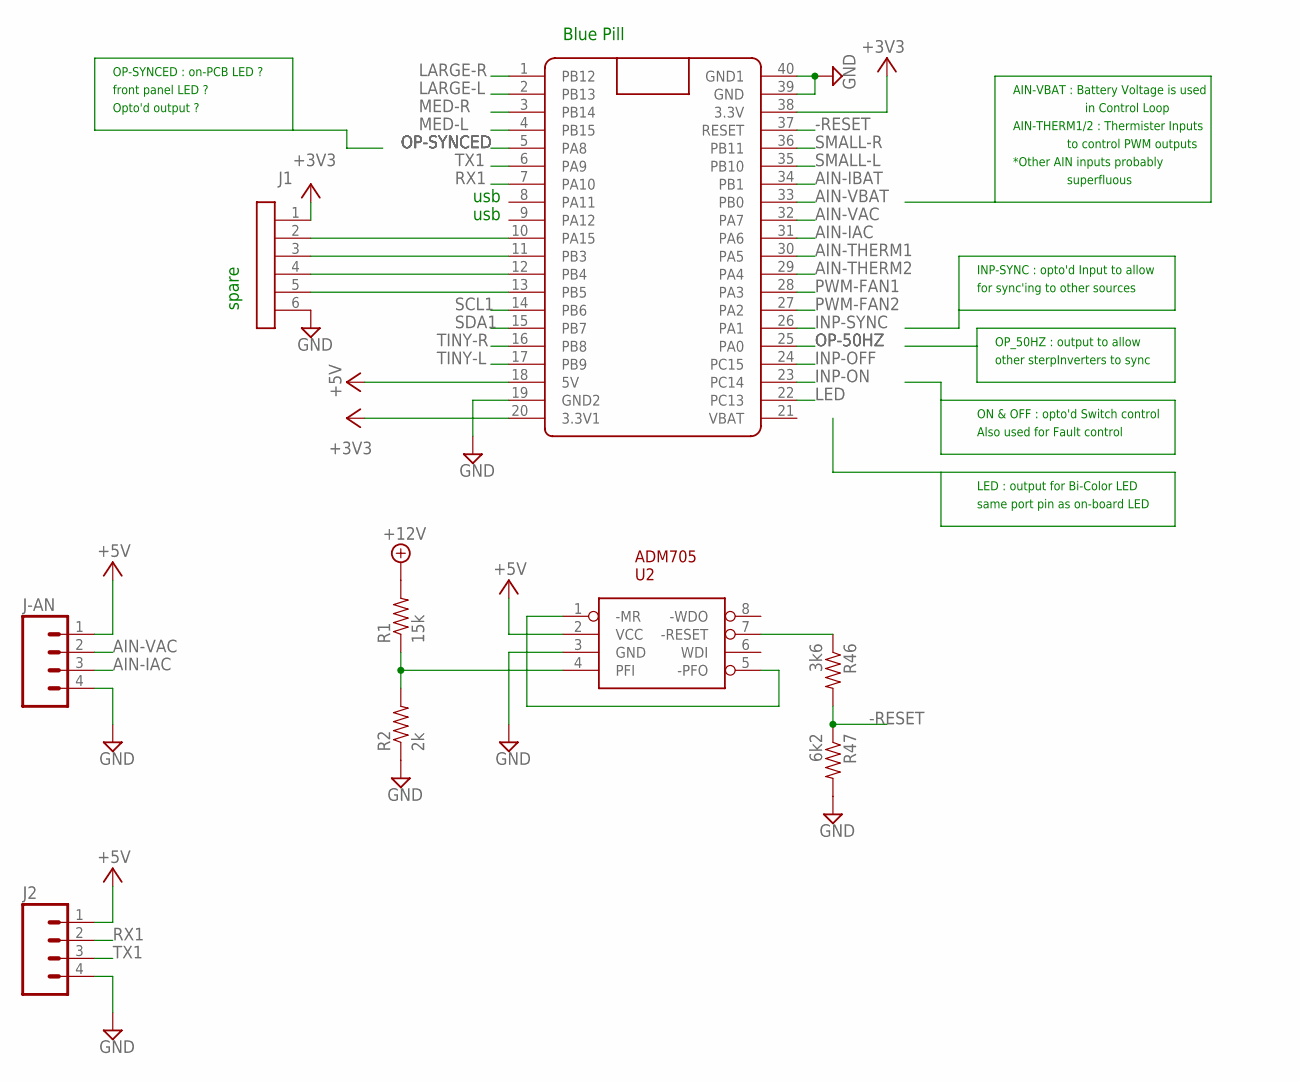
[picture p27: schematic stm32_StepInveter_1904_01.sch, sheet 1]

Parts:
J1: SIL-6; SIL6
J2: SIL4
J-AN: SIL4
R1: 15k; AXIAL-0.4
R2: 2k; AXIAL-0.4
R46: 3k6; AXIAL-0.4
R47: 6k2; AXIAL-0.4
U2: ADM705; DIL08
U$1: BLUE_PILL; BLUE_PILL_CLEAN

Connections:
+3V3: J1.1, U$1.20 (3.3V1), U$1.38 (3.3V); also elsewhere on the board
+5V: J2.1, J-AN.1, U2.2 (VCC), U$1.18 (5V); also elsewhere on the board
+12V: R1.P$2 (2); also elsewhere on the board
-RESET: R46.P$2 (2), R47.P$1 (1), U$1.37 (RESET)
AIN-IAC: J-AN.3, U$1.31 (PA6)
AIN-IBAT: U$1.34 (PB1); also elsewhere on the board
AIN-THERM1: U$1.30 (PA5); also elsewhere on the board
AIN-THERM2: U$1.29 (PA4); also elsewhere on the board
AIN-VAC: J-AN.2, U$1.32 (PA7)
AIN-VBAT: U$1.33 (PB0); also elsewhere on the board
GND: J1.6, J2.4, J-AN.4, R2.P$1 (1), R47.P$2 (2), U2.3 (GND), U$1.19 (GND2), U$1.39 (GND), U$1.40 (GND1); also elsewhere on the board
INP-OFF: U$1.24 (PC15); also elsewhere on the board
INP-ON: U$1.23 (PC14); also elsewhere on the board
INP-SYNC: U$1.26 (PA1); also elsewhere on the board
LARGE-L: U$1.2 (PB13); also elsewhere on the board
LARGE-R: U$1.1 (PB12); also elsewhere on the board
LED: U$1.22 (PC13); also elsewhere on the board
MED-L: U$1.4 (PB15); also elsewhere on the board
MED-R: U$1.3 (PB14); also elsewhere on the board
unnamed: J1.2, U$1.10 (PA15)
unnamed: J1.3, U$1.11 (PB3)
unnamed: J1.4, U$1.12 (PB4)
unnamed: J1.5, U$1.13 (PB5)
unnamed: U2.1 (-MR), U2.5 (-PFO)
unnamed: R1.P$1 (1), R2.P$2 (2), U2.4 (PFI)
unnamed: R46.P$1 (1), U2.7 (-RESET)
OP-50HZ: U$1.25 (PA0); also elsewhere on the board
OP-SYNCED: U$1.5 (PA8); also elsewhere on the board
PWM-FAN1: U$1.28 (PA3); also elsewhere on the board
PWM-FAN2: U$1.27 (PA2); also elsewhere on the board
RX1: J2.2, U$1.7 (PA10)
SCL1: U$1.14 (PB6)
SDA1: U$1.15 (PB7)
SMALL-L: U$1.35 (PB10); also elsewhere on the board
SMALL-R: U$1.36 (PB11); also elsewhere on the board
TINY-L: U$1.17 (PB9); also elsewhere on the board
TINY-R: U$1.16 (PB8); also elsewhere on the board
TX1: J2.3, U$1.6 (PA9)

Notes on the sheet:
usb
spare
Blue Pill
OP_50HZ : output to allow
other sterpInverters to sync
ON & OFF : opto'd Switch control
Also used for Fault control
LED : output for Bi-Color LED
same port pin as on-board LED
INP-SYNC : opto'd Input to allow
for sync'ing to other sources
OP-SYNCED : on-PCB LED ?
front panel LED ?
Opto'd output ?
AIN-VBAT : Battery Voltage is used
in Control Loop
AIN-THERM1/2 : Thermister Inputs
to control PWM outputs
*Other AIN inputs probably
superfluous

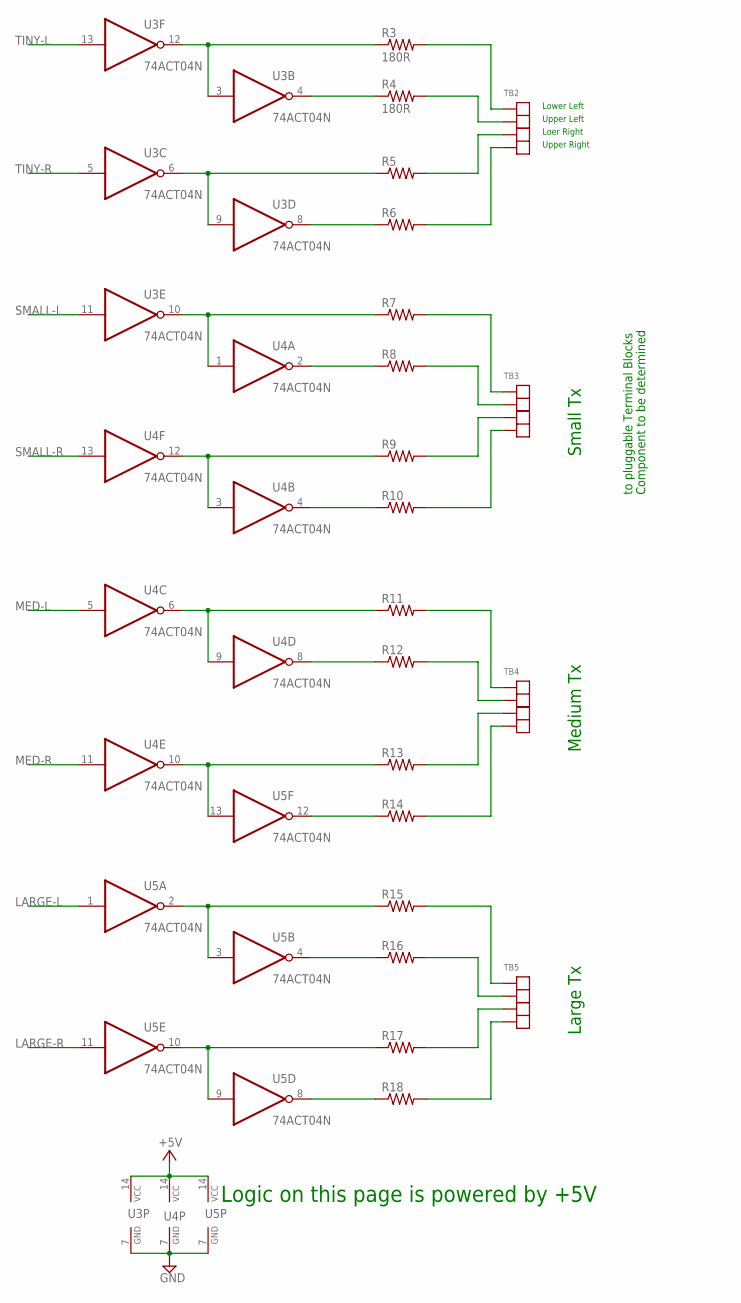
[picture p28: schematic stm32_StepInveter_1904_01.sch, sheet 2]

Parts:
R3, R4: 180R; AXIAL-0.4
R5, R6, R7, R8, R9, R10, R11, R12, R13, R14, R15, R16, R17, R18: R4; AXIAL-0.4
TB2, TB3, TB4, TB5: TB4381_SIL; TB-381-SIL-4P
U3, U4, U5: 74ACT04N; DIL14

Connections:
+5V: U3.14 (VCC), U4.14 (VCC), U5.14 (VCC); also elsewhere on the board
GND: U3.7 (GND), U4.7 (GND), U5.7 (GND); also elsewhere on the board
LARGE-L: U5.1 (I); also elsewhere on the board
LARGE-R: U5.11 (I); also elsewhere on the board
MED-L: U4.5 (I); also elsewhere on the board
MED-R: U4.11 (I); also elsewhere on the board
unnamed: R3.P$1 (1), U3.3 (I), U3.12 (O)
unnamed: R4.P$1 (1), U3.4 (O)
unnamed: R5.P$1 (1), U3.6 (O), U3.9 (I)
unnamed: R6.P$1 (1), U3.8 (O)
unnamed: R7.P$1 (1), U3.10 (O), U4.1 (I)
unnamed: R8.P$1 (1), U4.2 (O)
unnamed: R9.P$1 (1), U4.3 (I), U4.12 (O)
unnamed: R10.P$1 (1), U4.4 (O)
unnamed: R11.P$1 (1), U4.6 (O), U4.9 (I)
unnamed: R12.P$1 (1), U4.8 (O)
unnamed: R13.P$1 (1), U4.10 (O), U5.13 (I)
unnamed: R14.P$1 (1), U5.12 (O)
unnamed: R15.P$1 (1), U5.2 (O), U5.3 (I)
unnamed: R16.P$1 (1), U5.4 (O)
unnamed: R17.P$1 (1), U5.9 (I), U5.10 (O)
unnamed: R18.P$1 (1), U5.8 (O)
unnamed: R3.P$2 (2), TB2.1, TB2.11 (1)
unnamed: R4.P$2 (2), TB2.2, TB2.12 (2)
unnamed: R5.P$2 (2), TB2.3, TB2.13 (3)
unnamed: R6.P$2 (2), TB2.4, TB2.14 (4)
unnamed: R7.P$2 (2), TB3.1, TB3.11 (1)
unnamed: R8.P$2 (2), TB3.2, TB3.12 (2)
unnamed: R9.P$2 (2), TB3.3, TB3.13 (3)
unnamed: R10.P$2 (2), TB3.4, TB3.14 (4)
unnamed: R11.P$2 (2), TB4.1, TB4.11 (1)
unnamed: R12.P$2 (2), TB4.2, TB4.12 (2)
unnamed: R13.P$2 (2), TB4.3, TB4.13 (3)
unnamed: R14.P$2 (2), TB4.4, TB4.14 (4)
unnamed: R15.P$2 (2), TB5.1, TB5.11 (1)
unnamed: R16.P$2 (2), TB5.2, TB5.12 (2)
unnamed: R17.P$2 (2), TB5.3, TB5.13 (3)
unnamed: R18.P$2 (2), TB5.4, TB5.14 (4)
SMALL-L: U3.11 (I); also elsewhere on the board
SMALL-R: U4.13 (I); also elsewhere on the board
TINY-L: U3.13 (I); also elsewhere on the board
TINY-R: U3.5 (I); also elsewhere on the board

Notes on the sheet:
Logic on this page is powered by +5V
to pluggable Terminal Blocks
Component to be determined
Lower Left
Upper Left
Loer Right
Upper Right
Large Tx
Medium Tx
Small Tx

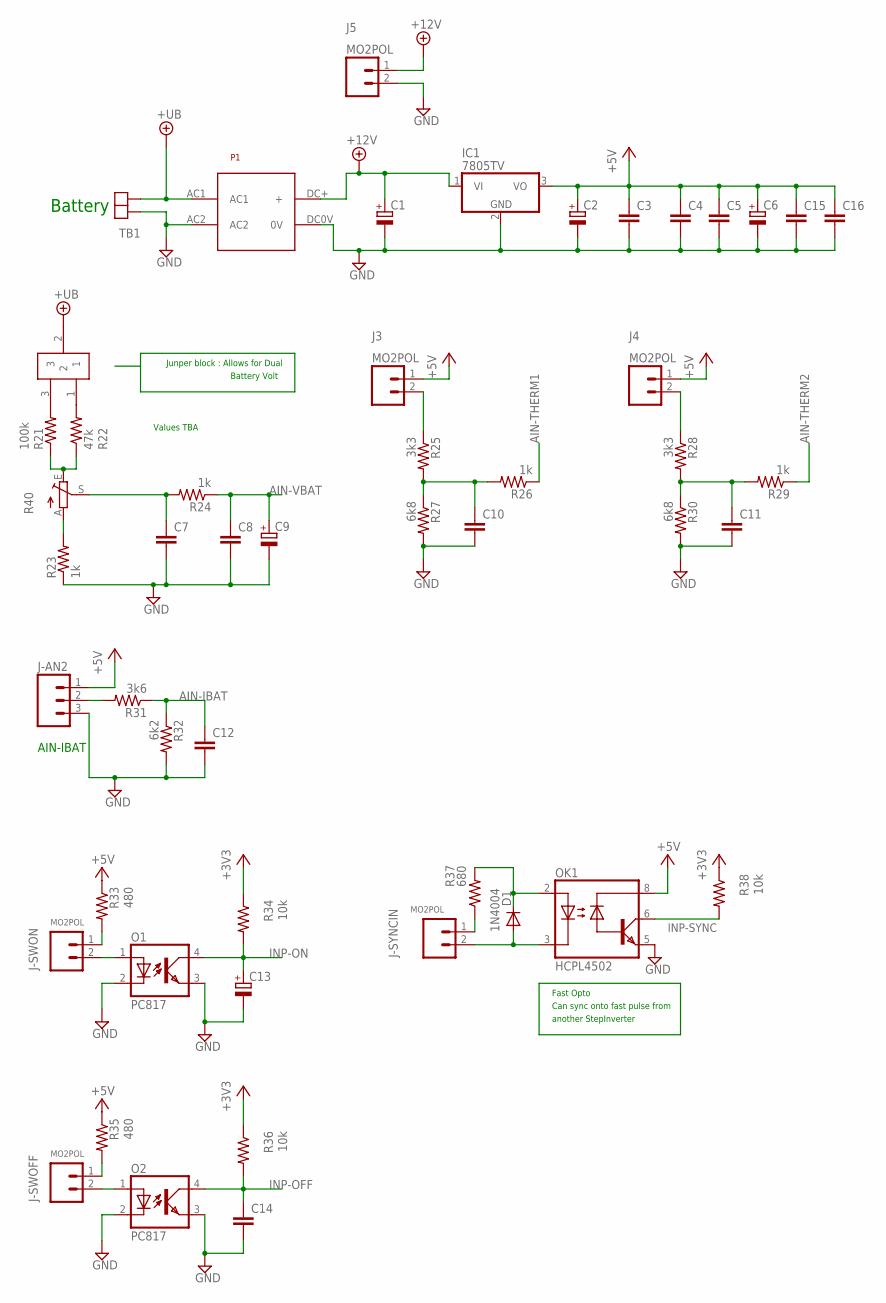
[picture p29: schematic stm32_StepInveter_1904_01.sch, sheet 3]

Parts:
C1: CPOL-EUE5-8.5; E5-8,5
C2, C6, C9: CPOL-EUE2.5-5; E2,5-5
C3, C4, C5, C7, C8, C10, C11, C12, C14, C15, C16: BCAP
C13: CPOL-EUE2.5-6; E2,5-6
D1: 1N4004; DO41-10
IC1: 7805TV; TO220V
J3, J4, J5: MO2POL; MOLEX-1X2
J-AN2: MO3POL; MOLEX-3
J-SWOFF: MO2POL; MOLEX-1X2
J-SWON: MO2POL; MOLEX-1X2
J-SYNCIN: MO2POL; MOLEX-1X2
JP1: JP1X3
O1, O2: PC817; DIL04
OK1: HCPL4502; DIL08
P1: ACDC
R21: 100k; AXIAL-0.4
R22: 47k; AXIAL-0.4
R23, R24, R26, R29: 1k; AXIAL-0.4
R25, R28: 3k3; AXIAL-0.4
R27, R30: 6k8; AXIAL-0.4
R31: 3k6; AXIAL-0.4
R32: 6k2; AXIAL-0.4
R33, R35: 480; AXIAL-0.4
R34, R36, R38: 10k; AXIAL-0.4
R37: 680; AXIAL-0.4
R40: TRIM_EU-B64Y; B64Y
TB1: TB2381; TB-KF2EDG381-2P

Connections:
+3V3: R34.P$1 (1), R36.P$1 (1), R38.P$1 (1); also elsewhere on the board
+5V: C2.+, C3.1, C4.1, C5.1, C6.+, C15.1, C16.1, IC1.3 (VO), J3.1, J4.1, J-AN2.1, OK1.8 (VCC), R33.P$1 (1), R35.P$1 (1); also elsewhere on the board
+12V: C1.+, IC1.1 (VI), J5.1, P1.DC+ (+); also elsewhere on the board
+UB: JP1.2, P1.AC1, TB1.1
AIN-IBAT: C12.1, R31.P$1 (1), R32.P$1 (1); also elsewhere on the board
AIN-THERM1: R26.P$1 (1); also elsewhere on the board
AIN-THERM2: R29.P$1 (1); also elsewhere on the board
AIN-VBAT: C8.1, C9.+, R24.P$1 (1); also elsewhere on the board
GND: C1.-, C2.-, C3.2, C4.2, C5.2, C6.-, C7.2, C8.2, C9.-, C10.2, C11.2, C12.2, C13.-, C14.2, C15.2, C16.2, IC1.2 (GND), J5.2, J-AN2.3, O1.2 (C), O1.3 (EMIT), O2.2 (C), O2.3 (EMIT), OK1.5 (GND), P1.AC2, P1.DC0V (0V), R23.P$1 (1), R27.P$2 (2), R30.P$2 (2), R32.P$2 (2), TB1.2; also elsewhere on the board
INP-OFF: C14.1, O2.4 (COL), R36.P$2 (2); also elsewhere on the board
INP-ON: C13.+, O1.4 (COL), R34.P$2 (2); also elsewhere on the board
INP-SYNC: OK1.6 (VO), R38.P$2 (2); also elsewhere on the board
unnamed: JP1.3, R21.P$2 (2)
unnamed: JP1.1, R22.P$2 (2)
unnamed: R21.P$1 (1), R22.P$1 (1), R40.E
unnamed: C10.1, R25.P$2 (2), R26.P$2 (2), R27.P$1 (1)
unnamed: J4.2, R28.P$1 (1)
unnamed: J3.2, R25.P$1 (1)
unnamed: C11.1, R28.P$2 (2), R29.P$2 (2), R30.P$1 (1)
unnamed: J-SWON.1, R33.P$2 (2)
unnamed: J-AN2.2, R31.P$2 (2)
unnamed: J-SWON.2, O1.1 (A)
unnamed: J-SYNCIN.1, R37.P$1 (1)
unnamed: D1.A, J-SYNCIN.2, OK1.3 (C)
unnamed: J-SWOFF.1, R35.P$2 (2)
unnamed: J-SWOFF.2, O2.1 (A)
unnamed: D1.C, OK1.2 (A), R37.P$2 (2)
unnamed: C7.1, R24.P$2 (2), R40.S
unnamed: R23.P$2 (2), R40.A

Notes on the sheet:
Battery
Values TBA
Junper block : Allows for Dual
Battery Volt
AIN-IBAT
Fast Opto
Can sync onto fast pulse from
another StepInverter

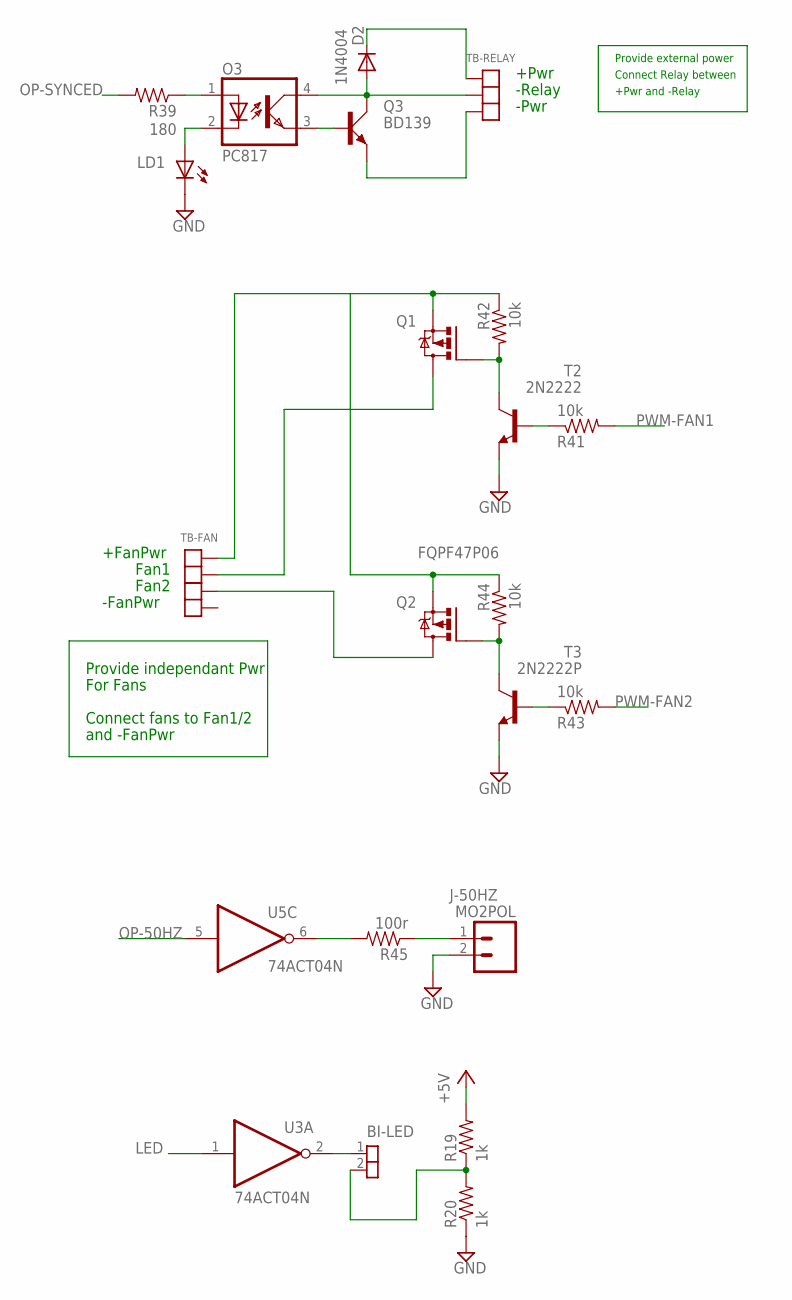
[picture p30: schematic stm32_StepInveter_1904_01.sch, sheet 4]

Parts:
BI-LED: SIL-2; JP1
D2: 1N4004; DO41-10
J-50HZ: MO2POL; MOLEX-1X2
LD1: LED3MM
O3: PC817; DIL04
Q1: MOSFET-PCHFQPF47P06; TO220BV
Q2: FQPF47P06; TO220BV
Q3: BD139; TO126AV
R19, R20: 1k; AXIAL-0.4
R39: 180; AXIAL-0.4
R41, R42, R43, R44: 10k; AXIAL-0.4
R45: 100r; AXIAL-0.4
T2: 2N2222; TO92/
T3: 2N2222P; TO92/
TB-FAN: TB4; TB-KF2EDG381-4P
TB-RELAY: TB3381; TB-KF2EDG381-3P
U3, U5: 74ACT04N; DIL14

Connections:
+5V: R19.P$2 (2); also elsewhere on the board
GND: J-50HZ.2, LD1.K (C), R20.P$1 (1), T2.1 (E), T3.1 (E); also elsewhere on the board
LED: U3.1 (I); also elsewhere on the board
unnamed: BI-LED.2, R19.P$1 (1), R20.P$2 (2)
unnamed: BI-LED.1, U3.2 (O)
unnamed: LD1.A, O3.2 (C)
unnamed: O3.1 (A), R39.P$1 (1)
unnamed: Q1.G, R42.P$2 (2), T2.3 (C)
unnamed: O3.3 (EMIT), Q3.B
unnamed: R41.P$1 (1), T2.2 (B)
unnamed: Q1.S, Q2.S, R42.P$1 (1), R44.P$1 (1), TB-FAN.1
unnamed: Q2.G, R44.P$2 (2), T3.3 (C)
unnamed: R45.P$2 (2), U5.6 (O)
unnamed: Q1.D, TB-FAN.2
unnamed: R43.P$1 (1), T3.2 (B)
unnamed: J-50HZ.1, R45.P$1 (1)
unnamed: Q2.D, TB-FAN.3
unnamed: D2.A, O3.4 (COL), Q3.C, TB-RELAY.2
unnamed: D2.C, TB-RELAY.1
unnamed: Q3.E, TB-RELAY.3
OP-50HZ: U5.5 (I); also elsewhere on the board
OP-SYNCED: R39.P$2 (2); also elsewhere on the board
PWM-FAN1: R41.P$2 (2); also elsewhere on the board
PWM-FAN2: R43.P$2 (2); also elsewhere on the board

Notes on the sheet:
+FanPwr
-FanPwr
Fan1
Fan2
Provide independant Pwr
For Fans
Connect fans to Fan1/2
and -FanPwr
+Pwr
-Pwr
-Relay
Connect Relay between
+Pwr and -Relay
Provide external power

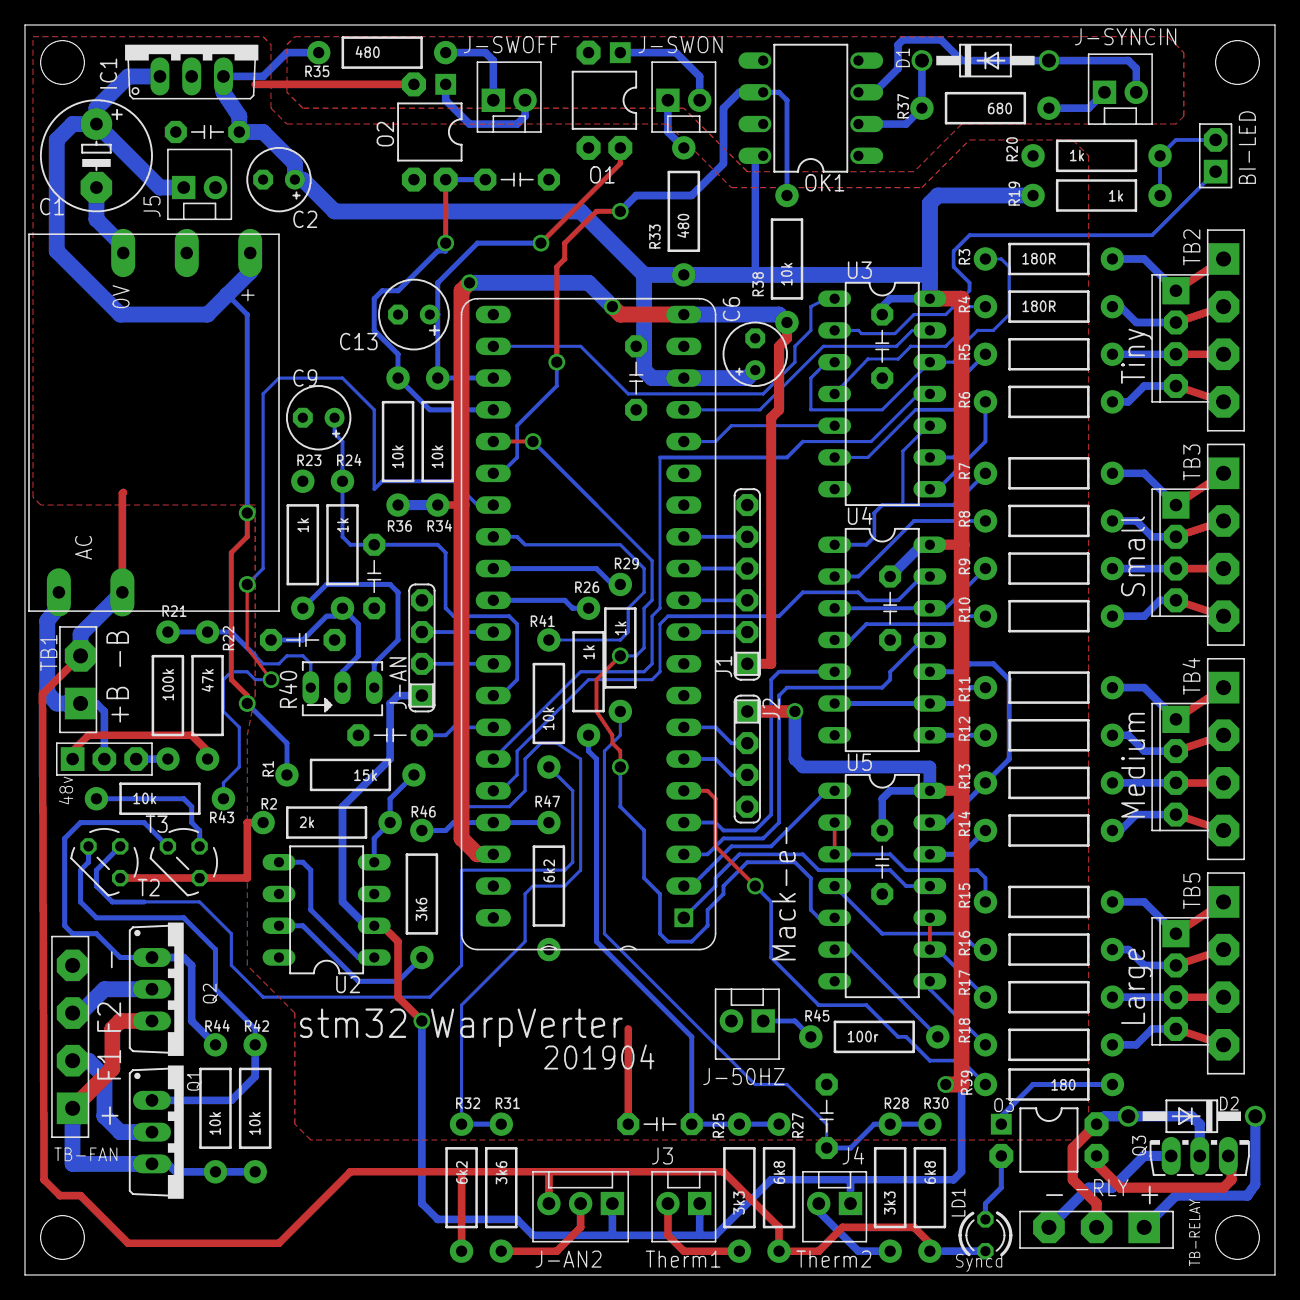
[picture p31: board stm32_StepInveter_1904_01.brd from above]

Board: 2 copper layers, 100.0 x 100.0 mm, 102 parts (0 on the bottom side), 103 nets.

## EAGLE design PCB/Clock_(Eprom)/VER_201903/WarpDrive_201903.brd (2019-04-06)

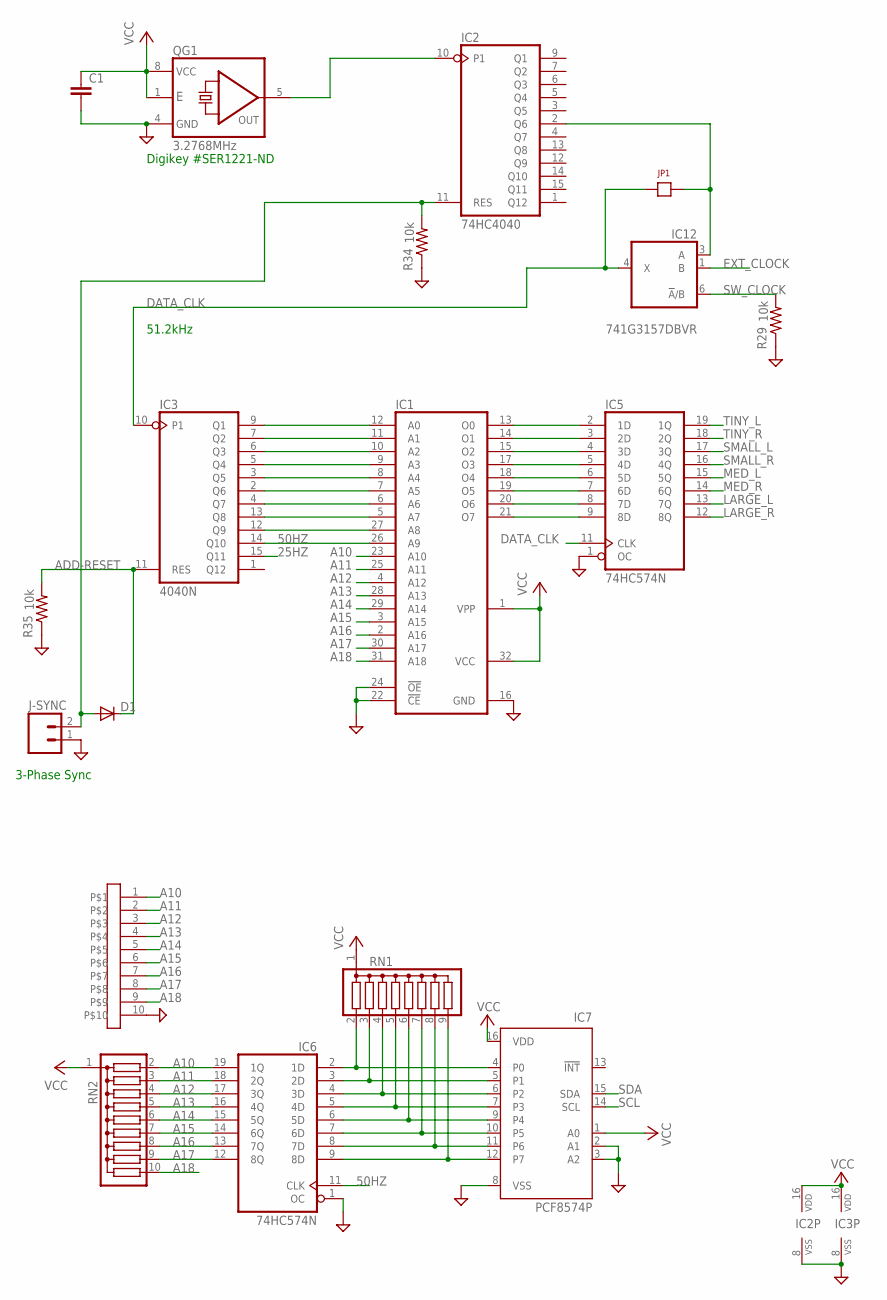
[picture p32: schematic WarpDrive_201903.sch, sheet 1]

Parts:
C1: BCAP
D1: 1N4148DO35-7; D3
IC1: 27C4001D; DIL32
IC2: 74HC4040; DIL16
IC3: 4040N; DIL16
IC5, IC6: 74HC574N; DIL20
IC7: PCF8574P; DIL16
IC12: 741G3157DBVR; DBV_R-PDSO-G6
J1: SIL-STACK-10
J-SYNC: MO2POL; MOLEX-1X2
JP1: JP1
QG1: 3.2768MHz; DIL08-4
R29, R34, R35: 10k; AXIAL-0.4
RN1: G08R; SIL9
RN2: G09R; SIL10

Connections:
25HZ: IC3.15 (Q11)
50HZ: IC1.26 (A9), IC3.14 (Q10), IC6.11 (CLK); also elsewhere on the board
A10: IC1.23 (A10), IC6.19 (1Q), J1.1, RN2.2
A11: IC1.25 (A11), IC6.18 (2Q), J1.2, RN2.3
A12: IC1.4 (A12), IC6.17 (3Q), J1.3, RN2.4
A13: IC1.28 (A13), IC6.16 (4Q), J1.4, RN2.5
A14: IC1.29 (A14), IC6.15 (5Q), J1.5, RN2.6
A15: IC1.3 (A15), IC6.14 (6Q), J1.6, RN2.7
A16: IC1.2 (A16), IC6.13 (7Q), J1.7, RN2.8
A17: IC1.30 (A17), IC6.12 (8Q), J1.8, RN2.9
A18: IC1.31 (A18), J1.9, RN2.10; also elsewhere on the board
ADD-RESET: D1.C, IC3.11 (RES), R35.P$2 (2); also elsewhere on the board
DATA_CLK: IC3.10 (P1), IC5.11 (CLK), IC12.4 (X), JP1.1; also elsewhere on the board
EXT_CLOCK: IC12.1 (B); also elsewhere on the board
GND: C1.2, IC1.16 (GND), IC1.22 (!CE), IC1.24 (!OE), IC2.8 (VSS), IC3.8 (VSS), IC5.1 (OC), IC5.10 (GND), IC6.1 (OC), IC6.10 (GND), IC7.2 (A1), IC7.3 (A2), IC7.8 (VSS), IC12.2 (GND), J1.10, J-SYNC.1, QG1.4 (GND), R29.P$1 (1), R34.P$1 (1), R35.P$1 (1); also elsewhere on the board
LARGE_L: IC5.13 (7Q); also elsewhere on the board
LARGE_R: IC5.12 (8Q); also elsewhere on the board
MED_L: IC5.15 (5Q); also elsewhere on the board
MED_R: IC5.14 (6Q); also elsewhere on the board
unnamed: IC2.10 (P1), QG1.5 (OUT)
unnamed: IC1.12 (A0), IC3.9 (Q1)
unnamed: IC1.11 (A1), IC3.7 (Q2)
unnamed: IC1.10 (A2), IC3.6 (Q3)
unnamed: IC1.9 (A3), IC3.5 (Q4)
unnamed: IC1.8 (A4), IC3.3 (Q5)
unnamed: IC1.7 (A5), IC3.2 (Q6)
unnamed: IC1.6 (A6), IC3.4 (Q7)
unnamed: IC1.5 (A7), IC3.13 (Q8)
unnamed: IC1.27 (A8), IC3.12 (Q9)
unnamed: IC1.13 (O0), IC5.2 (1D)
unnamed: IC2.2 (Q6), IC12.3 (A), JP1.2
unnamed: IC1.14 (O1), IC5.3 (2D)
unnamed: IC6.2 (1D), IC7.4 (P0), RN1.2
unnamed: IC1.15 (O2), IC5.4 (3D)
unnamed: IC1.17 (O3), IC5.5 (4D)
unnamed: IC1.18 (O4), IC5.6 (5D)
unnamed: IC1.19 (O5), IC5.7 (6D)
unnamed: IC1.20 (O6), IC5.8 (7D)
unnamed: IC1.21 (O7), IC5.9 (8D)
unnamed: IC6.3 (2D), IC7.5 (P1), RN1.3
unnamed: IC6.4 (3D), IC7.6 (P2), RN1.4
unnamed: IC6.5 (4D), IC7.7 (P3), RN1.5
unnamed: IC6.6 (5D), IC7.9 (P4), RN1.6
unnamed: IC6.7 (6D), IC7.10 (P5), RN1.7
unnamed: IC6.8 (7D), IC7.11 (P6), RN1.8
unnamed: IC6.9 (8D), IC7.12 (P7), RN1.9
unnamed: D1.A, IC2.11 (RES), J-SYNC.2, R34.P$2 (2)
SCL: IC7.14 (SCL); also elsewhere on the board
SDA: IC7.15 (SDA); also elsewhere on the board
SMALL_L: IC5.17 (3Q); also elsewhere on the board
SMALL_R: IC5.16 (4Q); also elsewhere on the board
SW_CLOCK: IC12.6 (!A!/B), R29.P$2 (2); also elsewhere on the board
TINY_L: IC5.19 (1Q); also elsewhere on the board
TINY_R: IC5.18 (2Q); also elsewhere on the board
VCC: C1.1, IC1.1 (VPP), IC1.32 (VCC), IC2.16 (VDD), IC3.16 (VDD), IC5.20 (VCC), IC6.20 (VCC), IC7.1 (A0), IC7.16 (VDD), IC12.5 (VCC), QG1.1 (E), QG1.8 (VCC), RN1.1, RN2.1; also elsewhere on the board

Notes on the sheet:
51.2kHz
3-Phase Sync
Digikey #SER1221-ND

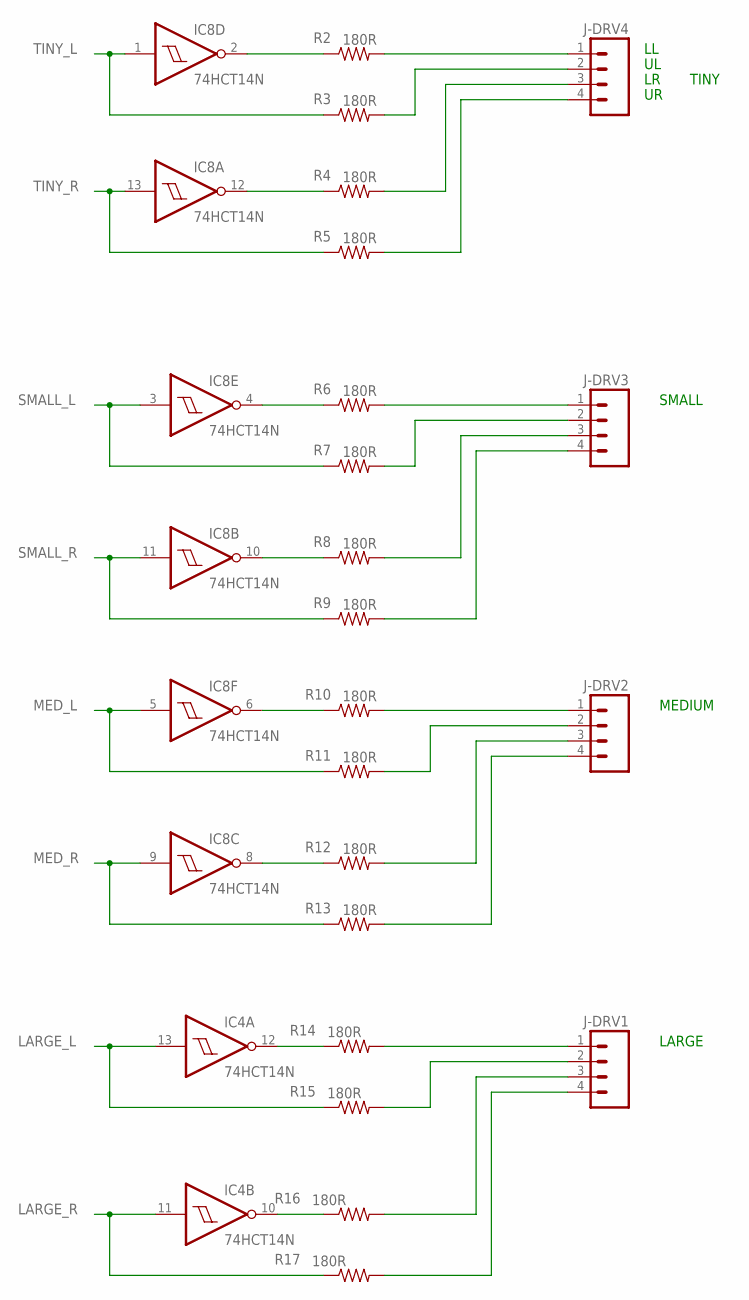
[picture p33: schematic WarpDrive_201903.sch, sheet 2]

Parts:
IC4, IC8: 74HCT14N; DIL14
J-DRV1, J-DRV2, J-DRV3, J-DRV4: MO4POL; MOLEX-4
R2, R3, R4, R5, R6, R7, R8, R9, R10, R11, R12, R13, R14, R15, R16, R17: 180R; AXIAL-0.4

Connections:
GND: IC4.7 (GND), IC8.7 (GND); also elsewhere on the board
LARGE_L: IC4.13 (I), R15.P$1 (1); also elsewhere on the board
LARGE_R: IC4.11 (I), R17.P$1 (1); also elsewhere on the board
MED_L: IC8.5 (I), R11.P$1 (1); also elsewhere on the board
MED_R: IC8.9 (I), R13.P$1 (1); also elsewhere on the board
unnamed: IC4.12 (O), R14.P$1 (1)
unnamed: IC4.10 (O), R16.P$1 (1)
unnamed: IC8.2 (O), R2.P$1 (1)
unnamed: J-DRV4.1, R2.P$2 (2)
unnamed: J-DRV4.2, R3.P$2 (2)
unnamed: IC8.12 (O), R4.P$1 (1)
unnamed: J-DRV4.3, R4.P$2 (2)
unnamed: J-DRV4.4, R5.P$2 (2)
unnamed: IC8.4 (O), R6.P$1 (1)
unnamed: J-DRV3.1, R6.P$2 (2)
unnamed: J-DRV3.2, R7.P$2 (2)
unnamed: IC8.10 (O), R8.P$1 (1)
unnamed: J-DRV3.3, R8.P$2 (2)
unnamed: J-DRV3.4, R9.P$2 (2)
unnamed: IC8.6 (O), R10.P$1 (1)
unnamed: J-DRV2.1, R10.P$2 (2)
unnamed: J-DRV2.2, R11.P$2 (2)
unnamed: IC8.8 (O), R12.P$1 (1)
unnamed: J-DRV2.3, R12.P$2 (2)
unnamed: J-DRV2.4, R13.P$2 (2)
unnamed: J-DRV1.1, R14.P$2 (2)
unnamed: J-DRV1.2, R15.P$2 (2)
unnamed: J-DRV1.3, R16.P$2 (2)
unnamed: J-DRV1.4, R17.P$2 (2)
SMALL_L: IC8.3 (I), R7.P$1 (1); also elsewhere on the board
SMALL_R: IC8.11 (I), R9.P$1 (1); also elsewhere on the board
TINY_L: IC8.1 (I), R3.P$1 (1); also elsewhere on the board
TINY_R: IC8.13 (I), R5.P$1 (1); also elsewhere on the board
VCC: IC4.14 (VCC), IC8.14 (VCC); also elsewhere on the board

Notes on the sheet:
TINY
SMALL
MEDIUM
LARGE

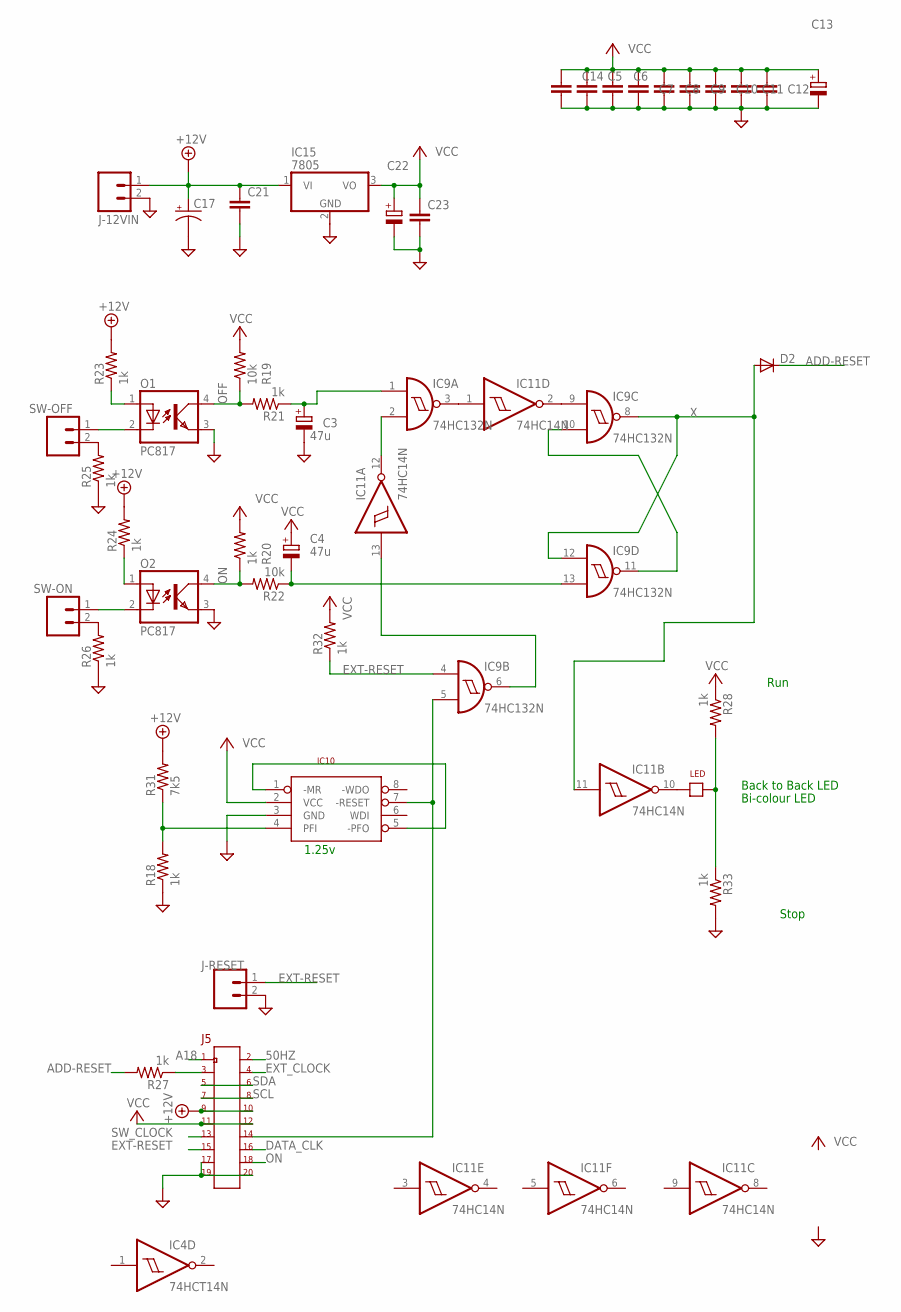
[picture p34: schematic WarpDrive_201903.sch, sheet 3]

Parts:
C3, C4: 47u; CPOL-RADIAL-10UF-25V
C5, C6, C7, C8, C9, C10, C11, C12, C14, C21, C23: BCAP
C13, C22: C-RB200100; CPOL-RADIAL-10UF-25V
C17: CAP_POLPTH1; CPOL-RADIAL-100UF-25V
D2: 1N4148DO35-7; D3
IC4: 74HCT14N; DIL14
IC9: 74HC132N; DIL14
IC10: ADM705; DIL08
IC11: 74HC14N; DIL14
IC15: 7805; TO220V
J5: IDC20IDC20-SMALL; IDC20-SMALL
J-12VIN: MO2POL; MOLEX-1X2
J-RESET: MO2POL; MOLEX-1X2
LED: JP1
O1, O2: PC817; DIL04
R18, R20, R21, R23, R24, R25, R26, R27, R28, R32, R33: 1k; AXIAL-0.4
R19, R22: 10k; AXIAL-0.4
R31: 7k5; AXIAL-0.4
SW-OFF: MO2POL; MOLEX-1X2
SW-ON: MO2POL; MOLEX-1X2

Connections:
50HZ: J5.2; also elsewhere on the board
+12V: C17.1 (+), C21.1, IC15.1 (VI), J5.9, J5.10, J-12VIN.1, R23.P$2 (2), R24.P$2 (2), R31.P$2 (2)
A18: J5.1; also elsewhere on the board
ADD-RESET: D2.C, R27.P$2 (2); also elsewhere on the board
DATA_CLK: J5.16; also elsewhere on the board
EXT-RESET: IC9.4 (I0), J5.15, J-RESET.1, R32.P$1 (1)
EXT_CLOCK: J5.4; also elsewhere on the board
GND: C3.2 (-), C5.2, C6.2, C7.2, C8.2, C9.2, C10.2, C11.2, C12.2, C13.2 (-), C14.2, C17.2 (-), C21.2, C22.2 (-), C23.2, IC4.7 (GND), IC9.7 (GND), IC10.3 (GND), IC11.7 (GND), IC15.2 (GND), J5.17, J5.19, J5.20, J-12VIN.2, J-RESET.2, O1.3 (EMIT), O2.3 (EMIT), R18.P$1 (1), R25.P$1 (1), R26.P$1 (1), R33.P$2 (2); also elsewhere on the board
unnamed: IC9.9 (I0), IC11.2 (O)
unnamed: LED.2, R28.P$2 (2), R33.P$1 (1)
unnamed: R25.P$2 (2), SW-OFF.2
unnamed: J5.3, R27.P$1 (1)
unnamed: R26.P$2 (2), SW-ON.2
unnamed: IC9.10 (I1), IC9.11 (O)
unnamed: C3.1 (+), IC9.1 (I0), R21.P$1 (1)
unnamed: IC9.3 (O), IC11.1 (I)
unnamed: C4.2 (-), IC9.13 (I1), R22.P$1 (1)
unnamed: O1.1 (A), R23.P$1 (1)
unnamed: O1.2 (C), SW-OFF.1
unnamed: O2.1 (A), R24.P$1 (1)
unnamed: O2.2 (C), SW-ON.1
unnamed: IC9.2 (I1), IC11.12 (O)
unnamed: IC9.6 (O), IC11.13 (I)
unnamed: IC9.5 (I1), IC10.7 (-RESET), J5.14
unnamed: IC10.1 (-MR), IC10.5 (-PFO)
unnamed: IC10.4 (PFI), R18.P$2 (2), R31.P$1 (1)
unnamed: IC11.10 (O), LED.1
OFF: O1.4 (COL), R19.P$1 (1), R21.P$2 (2)
ON: J5.18, O2.4 (COL), R20.P$1 (1), R22.P$2 (2)
SCL: J5.7, J5.8; also elsewhere on the board
SDA: J5.5, J5.6; also elsewhere on the board
SW_CLOCK: J5.13; also elsewhere on the board
VCC: C4.1 (+), C5.1, C6.1, C7.1, C8.1, C9.1, C10.1, C11.1, C12.1, C13.1 (+), C14.1, C22.1 (+), C23.1, IC4.14 (VCC), IC9.14 (VCC), IC10.2 (VCC), IC11.14 (VCC), IC15.3 (VO), J5.11, J5.12, R19.P$2 (2), R20.P$2 (2), R28.P$1 (1), R32.P$2 (2); also elsewhere on the board
X: D2.A, IC9.8 (O), IC9.12 (I0), IC11.11 (I)

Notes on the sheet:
1.25v
Run
Stop
Back to Back LED
Bi-colour LED

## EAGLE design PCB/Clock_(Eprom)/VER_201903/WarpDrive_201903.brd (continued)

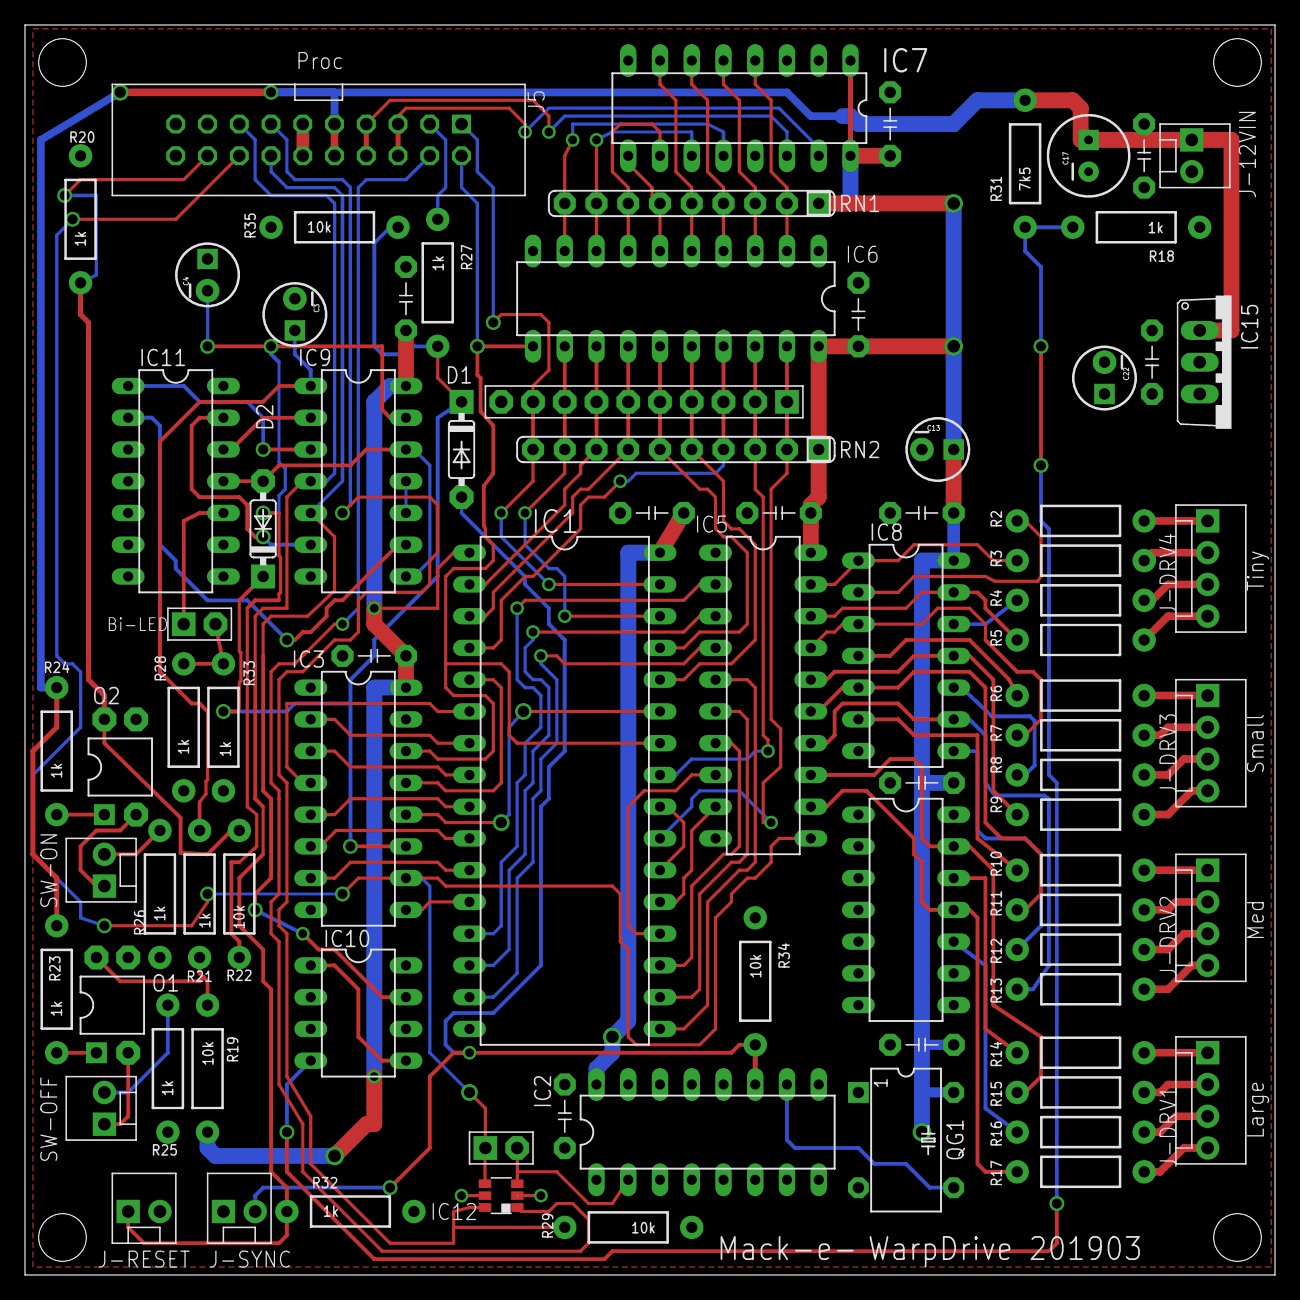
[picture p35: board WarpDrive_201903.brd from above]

Board: 2 copper layers, 100.0 x 100.0 mm, 83 parts (0 on the bottom side), 102 nets.

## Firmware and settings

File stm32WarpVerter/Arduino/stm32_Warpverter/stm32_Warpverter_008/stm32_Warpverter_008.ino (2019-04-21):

#include <Streaming.h>
#include <PString.h>
#include <STM32ADC.h>

STM32ADC adcV(ADC2);
STM32ADC adc_2(ADC1);

uint8 adcPinV = PB0;
uint8 adcPinI = PB1;

#define PIN_SYNCINP PA1
#define pinSwOff    PC15
#define pinSwON     PC14
#define pinFAN1     PA3
#define pinFAN2     PA2
#define pinRelay    PA8

#define setRelay gpio_write_bit(GPIOA, 8, HIGH)
#define clrRelay gpio_write_bit(GPIOA, 8, LOW)

#define setFAN1 gpio_write_bit(GPIOA, 3, HIGH)
#define clrFAN1 gpio_write_bit(GPIOA, 3, LOW)

#define setFAN2 gpio_write_bit(GPIOA, 2, HIGH)
#define clrFAN2 gpio_write_bit(GPIOA, 2, LOW)

#define pin50Hz PA0
#define set50Hz gpio_write_bit(GPIOA, 0, LOW)
#define clr50Hz gpio_write_bit(GPIOA, 0, HIGH)

#define clrPB5 gpio_write_bit(GPIOB, 5, LOW)
#define setPB5 gpio_write_bit(GPIOB, 5, HIGH)

#define clrPB4 gpio_write_bit(GPIOB, 4, LOW)
#define setPB4 gpio_write_bit(GPIOB, 4, HIGH)

#define clrPA15 gpio_write_bit(GPIOA, 15, LOW)
#define setPA15 gpio_write_bit(GPIOA, 15, HIGH)

volatile uint16 adcValueV;
volatile uint16 adcValueI;

volatile int32 avgADC_V;
//volatile int32 avgADC_I;

byte  outputDrive = 0;    // Output Driver : High Byte of PORT B 
uint16 cycleIndex;           // position within the cycle : between 0 to 1023 , 
int32 inputFactor = 10000;

bool inverterRunning = false;
int16 onPressed;
bool fan1ON = false;
bool fan2ON = false;

HardwareTimer inverterTimer(3);//4

#define PIN_THERM1 PA5
#define PIN_THERM2 PA4
#define PIN_VAC    PA7
#define PIN_IAC    PA6



uint8 analogInputs[] = {PIN_THERM1,PIN_THERM2,adcPinI,PIN_VAC,PIN_IAC};
uint16_t adcData[5];

#define STEPS 1024
#define VOLTSTEPS   int(pow(3,TRANSFORMER_COUNT))
#define VOLT_MASK_TABLE flash_voltMaskTable
#define SINE_LOOKUP_TABLE flash_sineLookup

#define adcTherm1  adcData[0]
#define adcTherm2  adcData[1]
#define avgADC_I   adcData[2]

char message[256];
PString pMessage(message,sizeof(message));

#define LED      PC13


//
// mains sync
//
long pcount_acc;
int pcount_delta, phase_error, old_phase_error;
int int_f,p_lock;






void loop() {
  // put your main code here, to run repeatedly:

}

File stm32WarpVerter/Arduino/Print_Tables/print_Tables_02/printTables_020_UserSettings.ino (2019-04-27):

/*-------------------------------------------------------------------------------
 * 
 *          USER DEFINED VALUES
 *          ________________________
 *          
 *          INVERTER_TITLE          :  Useful title todescribe this setup( inside " ")
 *                              
 *          THEFACTORTABLE          :  Sets whether you use "theTable" ; Comment this line out to disable.      
 *                                     - "theTable" is 64k in size so you must have a 128k Blue Pill  (most are it seems)
 *                                     - Uses "WATT_PER_AC_VOLTDROP" 
 *                                     - If enabled, Output Regulation should be more accurate.
 *                                     - If disabled, warpverter uses "InputFactorTable" and "currentFactorTable"
 *                              
 *          NOMINAL_VAC : Whole integer value
 *                        -  Is the output RMS AC value you expect AT the     
 *                          nominal Battery Voltage.
 *                        
 *          NOMINAL_BATTERY_VOLTAGE  :  Whole integer value
 *                                      -  Expressed in millivolts.
 *                                      -  This is the Battery Voltage for 
 *                                        which the transformers turns ratio
 *                                        results in the Nominal RMS AC voltage.
 *           
 *           TRANSFORMER_COUNT  :  Number of transformers in Inverter. (Max 4)
 *            
 *           
 *                       
 *           BATTERY_VOLTAGE_AT_MAX_ADC  :  Whole integer value.
 *                                          -  Expressed in milliVolts.
 *                                          -  This is the Maximum Battery Voltage 
 *                                            value read by the ADC(analog to digital converter).
 *                                          -  Put another way.  This is the Battery Voltage 
 *                                            that when divided down and feed into the ADC is 3.3 volts.
 *                                          -  Ensure 3.3volts is not exceeded or damage may result.
 *                                          
 *           BATTERY_LOW_CUTOFF :       Whole integer value
 *                                      -  Expressed in milliVolts
 *                                      -  Inverter will turn off at this level.                               
 *                                 
 *           BATTERY_HIGH_CUTOFF         Whole integer value
 *                                      -  Expressed in milliVolts
 *                                      -  Inverter will turn off at this level.              
 *                                      
 *           ADC_VALUE_ZERO_DC_CURRENT :    Range 0 - 4095                           
 *                                          - Current transducers often have their 
 *                                           Zero reference at half way.
 *                                          -  Typically 2048
 *                                          
 *           DC_CURRENT_AT_MAX_ADC      :   Value in milliAmps at Maximum ADC range.                        
 *           
 *           DC_CURRENT_CUTOFF          :   Value in milliAmps, DC Current above this level 
 *                                          will shut down Inverter.
 *                                          
 *           DC_CURRENT_PER_AC_VOLTDROP :   Use this setting if "THEFACTORTABLE" is commented out.
 *                                          -  Value in milliAmps.
 *                                          -  Used as a proxy for Power.
 *                                          -  The amount of current which causes
 *                                             one volt RMS drop on the output.
 *                                             
 *           WATT_PER_AC_VOLTDROP        :  Use this setting if using "THEFACTORTABLE" 
 *                                          -  Value in Watts.
 *                                          -  The amount of Power which causes
 *                                             one volt RMS drop on the output.
 * 
 ---------------------------------------------------------------------------------*/


#define INVERTER_TITLE             "Tony, WarpSpeed's Inverter"

//#define THEFACTORTABLE             1          // comment this line out if Blue-Pill is 64k

#define NOMINAL_VAC                236
#define NOMINAL_BATTERY_VOLTAGE    90000      // in milliVolts
#define TRANSFORMER_COUNT          4
#define BATTERY_VOLTAGE_AT_MAX_ADC 180000     // milliVolts
#define BATTERY_LOW_CUTOFF         80000
#define BATTERY_HIGH_CUTOFF        180000

#define ADC_VALUE_ZERO_DC_CURRENT  2048      // half way to 4096 - being full scale
#define DC_CURRENT_AT_MAX_ADC      100000    // milliAmps
#define DC_CURRENT_CUTOFF          90000    // milliAmp
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

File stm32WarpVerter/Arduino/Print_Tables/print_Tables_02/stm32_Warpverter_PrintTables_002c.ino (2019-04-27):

#include <Streaming.h>
#include <math.h>


#define STEPS 1024
#define PRINT_TABLES 1


uint8 adc_temperatureTable[4096];
int temperature_adcTable[100];


void setup() {
  // put your setup code here, to run once:
  Serial.begin(57600);
  while (!Serial) 
   {
    ; // wait for serial port to connect. Needed for native USB port only
   }
  Serial << "stm32_Warpverter_Print_Tables" << endl;
  Serial.flush();
  delay(3000);
  
  setTransformerVoltage();

  Serial << "//-----------  Copy after This Line ----------" << endl << endl;
  fill_adc_temperatureTable();
  fill_temperature_adcTable();
  //calc_Xfactor();
  doPrintOuts();
  

  
}

void loop() {
  // put your main code here, to run repeatedly:

}

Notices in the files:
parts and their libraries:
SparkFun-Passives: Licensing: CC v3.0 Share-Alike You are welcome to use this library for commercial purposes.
